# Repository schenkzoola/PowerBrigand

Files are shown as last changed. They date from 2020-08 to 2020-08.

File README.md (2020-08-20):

# PowerBrigand

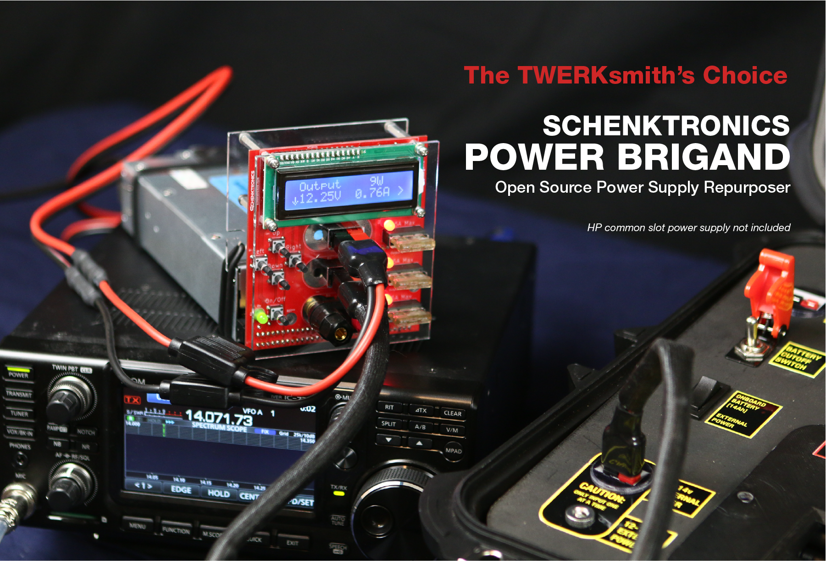
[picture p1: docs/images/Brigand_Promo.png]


## About

### How can I get it?

Well, you can build one yourself from the source files here, or better yet, you can join the waitlist for a kit from my Tindie store below:
[https://www.tindie.com/products/schenktronics/power-brigand/](https://www.tindie.com/products/schenktronics/power-brigand/)
The parts for the first batch of kits have been ordered! 

### What is it?

Power Brigand is a module that attaches to HP common slot power supplies that are normally used in servers.  It has connectors and/or binding posts to bring 12v power to your devices.  It also has controls which allow you to turn the power supply on and off, as well as display parameters such as voltage, current, and temperature from the i2c bus on the power supply.

### Why?

After leaving the cryptocurrency mining scene, I had quite a few of these power supplies.  They are plentiful on eBay, and therefore inexpensive.  I felt it wasn't worth my time trying to sell them, and wanted a way to repurpose them.  I was unimpressed with the typical breakout board available from eBay and Aliexpress.

### How?

I found a few resources to start with.  [This one](http://colintd.blogspot.com/2016/10/hacking-hp-common-slot-power-supplies.html) discussed the supply, and compared it to a similar Murata power supply.

The best source of information I found was [this github repo](https://github.com/raplin/DPS-1200FB) where the author, DrTune, reverse engineered a power supply by decompiling the firmware from the internal microcontroller.  DrTune created some sample python code to read and write data to and from the I2C bus.  This gave me information on which registers to query for the data.

Using an arduino nano, a bus pirate, and DrTune's python code as a guide, I was able to successfully read the I2C bus.  This encouraged me to create a PCB with an LCD, output terminals, and fuses.

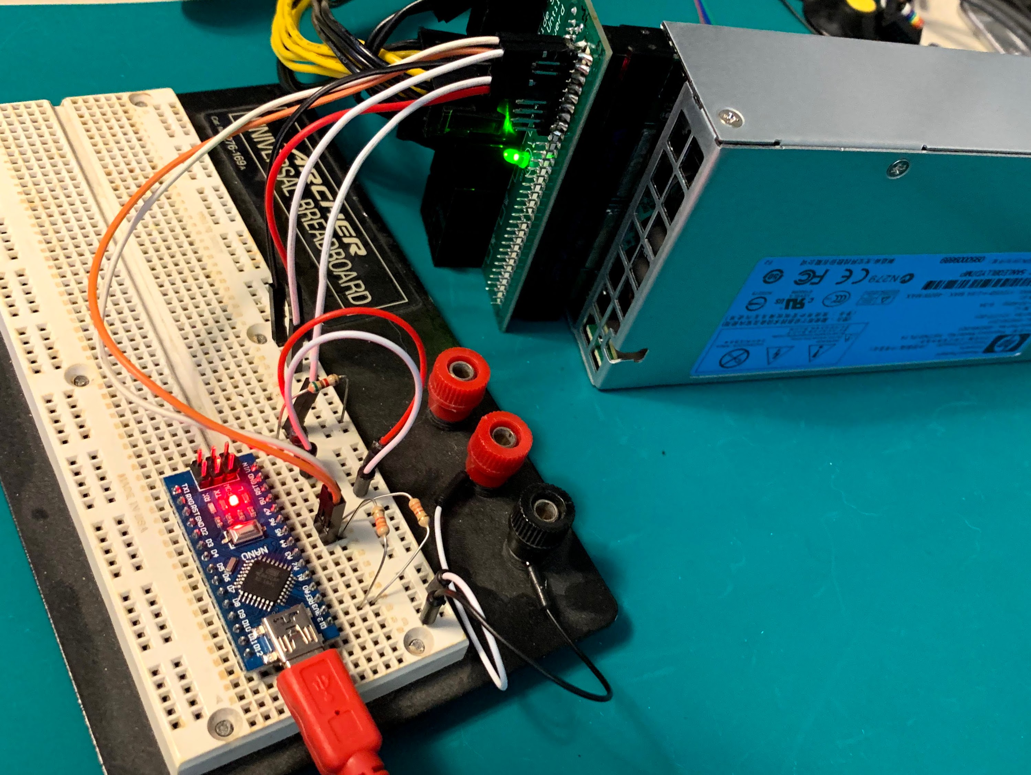
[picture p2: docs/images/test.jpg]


## Hardware

### Common Slot Power Supply

This is the heart of the Power Brigand, it won't work without one.
There are at least four commonly available versions of these power supplies: 460W, 750W, and two different 1200W versions.

#### 460W

This is the smallest of the power supplies, and the quietest.  Despite its small size, it is capable of producing 38.3A.  My testing has shown that this has the quietest fan, and the most sensitive current measurement capability.

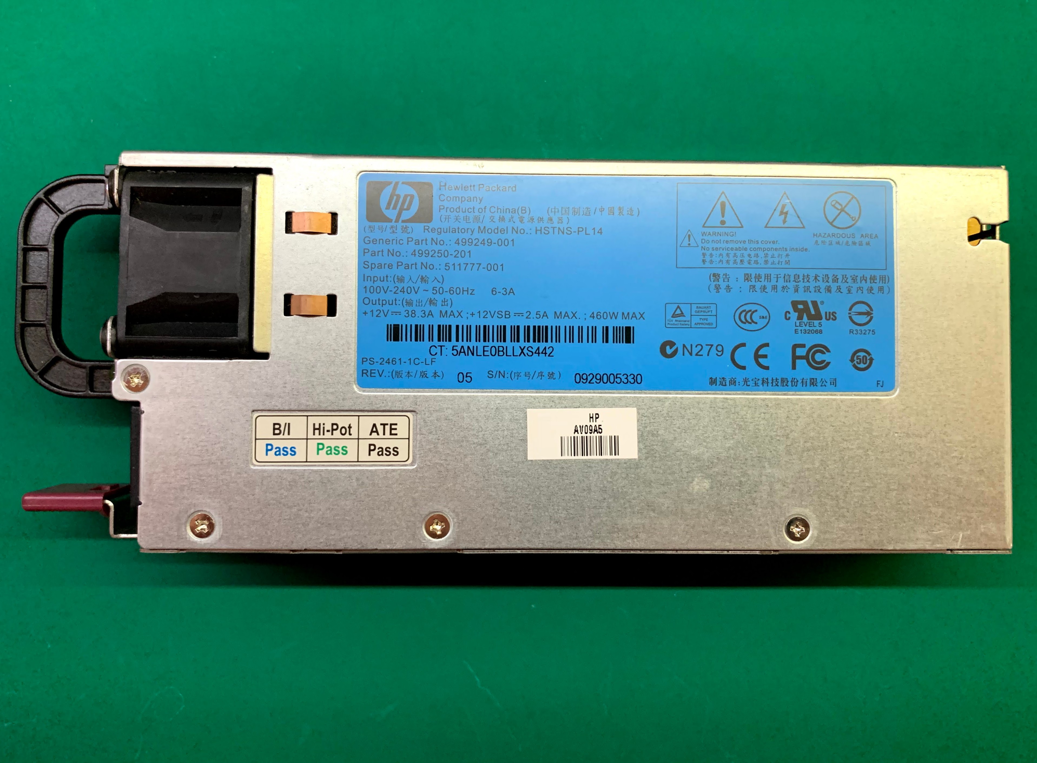
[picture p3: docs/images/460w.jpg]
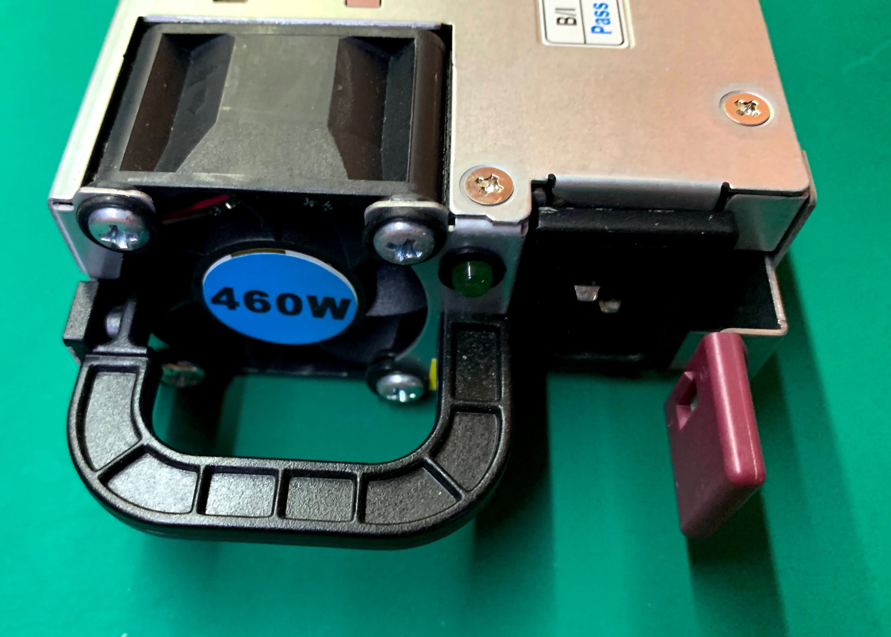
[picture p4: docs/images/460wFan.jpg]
 

#### 750W

This is the middle size power supply.  It can produce 62.5A.  Its fan is noisier than the 460W, and the minimum current it can accurately display is about 5A.

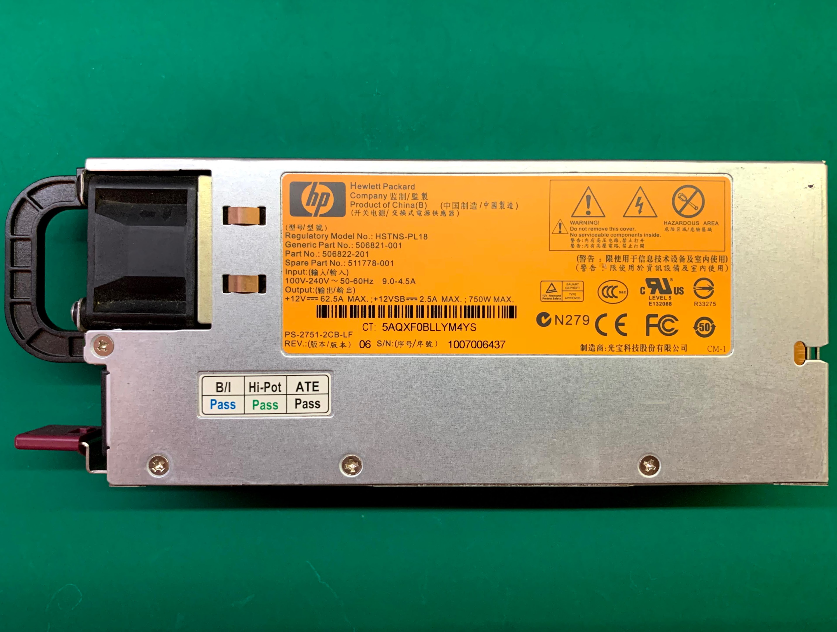
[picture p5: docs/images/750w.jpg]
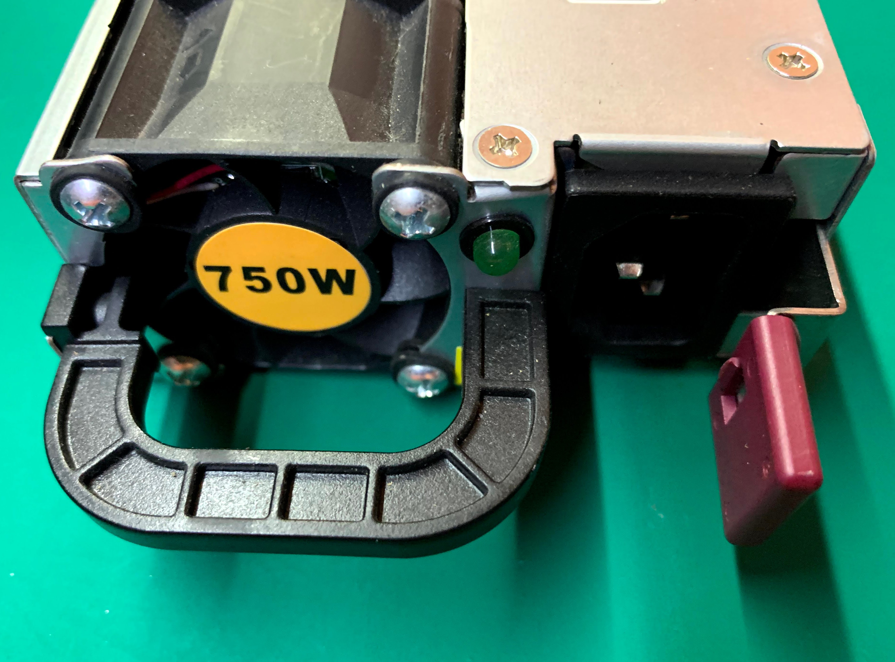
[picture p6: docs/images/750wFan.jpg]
 

#### 1200W

There are two 1200W power supplies, one is higher efficiency than the other.  They are sensitive to the input voltage.  At 120V they can only produce 75A. They require a 200V-240V power source to produce their full capability of 100A.  These power supplies also have a minimum accurate current display of about 5A, and they typically have noisier fans than the others.

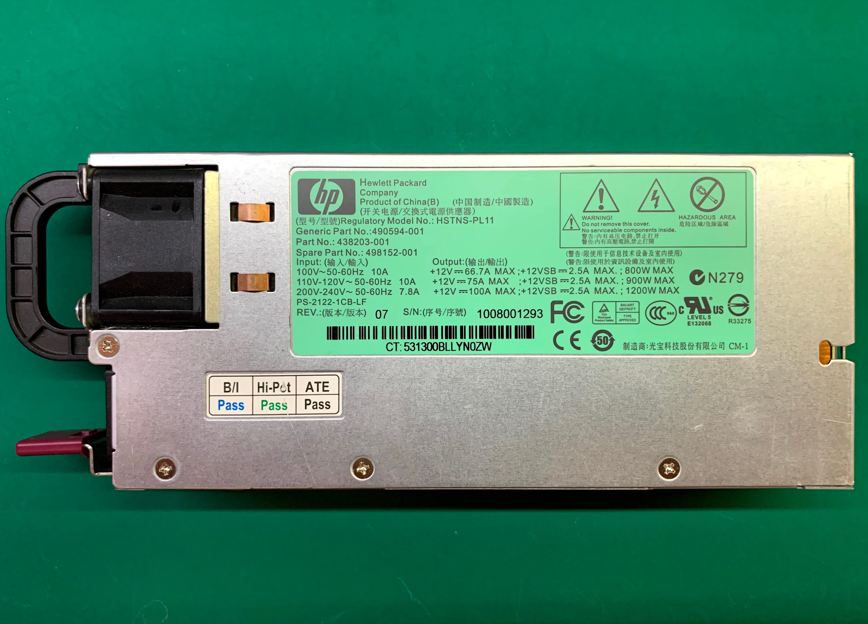
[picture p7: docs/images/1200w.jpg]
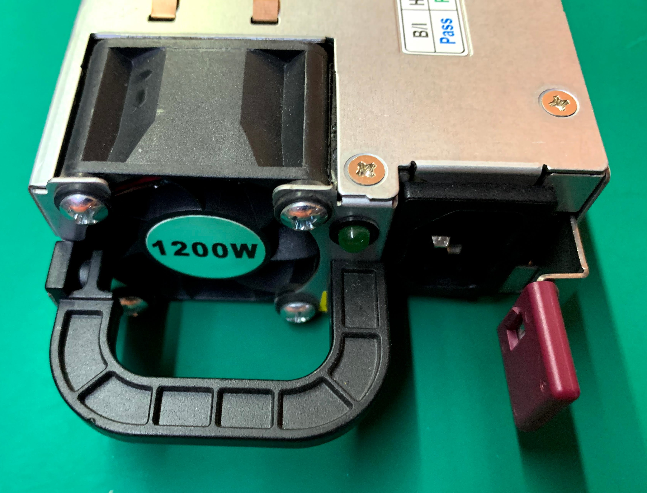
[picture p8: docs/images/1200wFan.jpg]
 
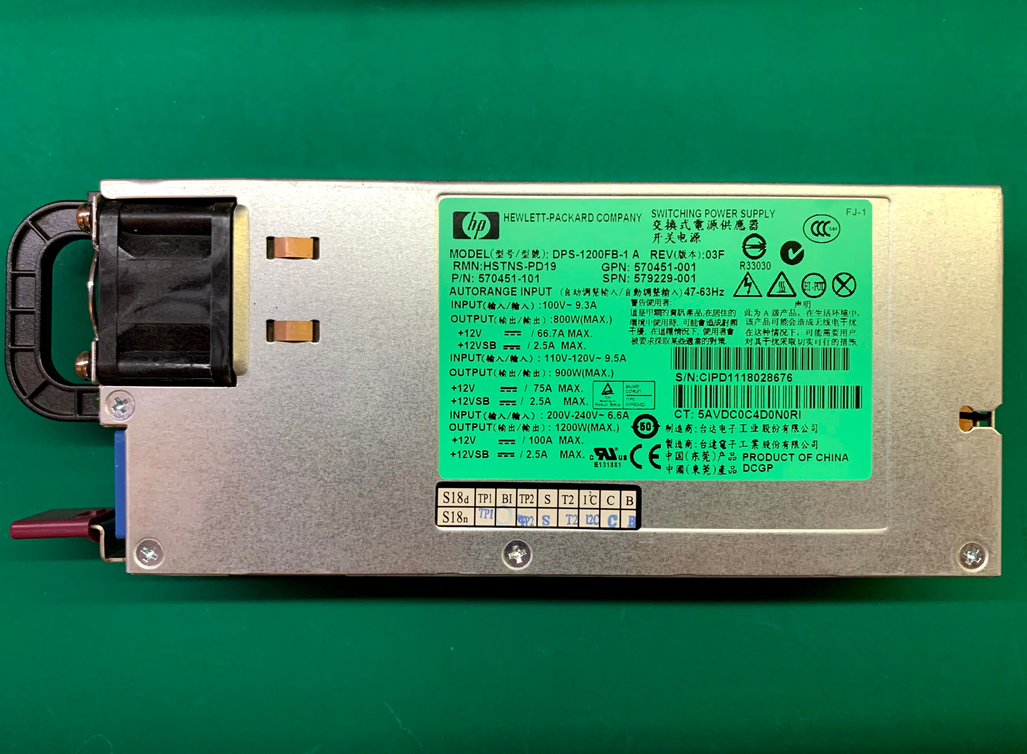
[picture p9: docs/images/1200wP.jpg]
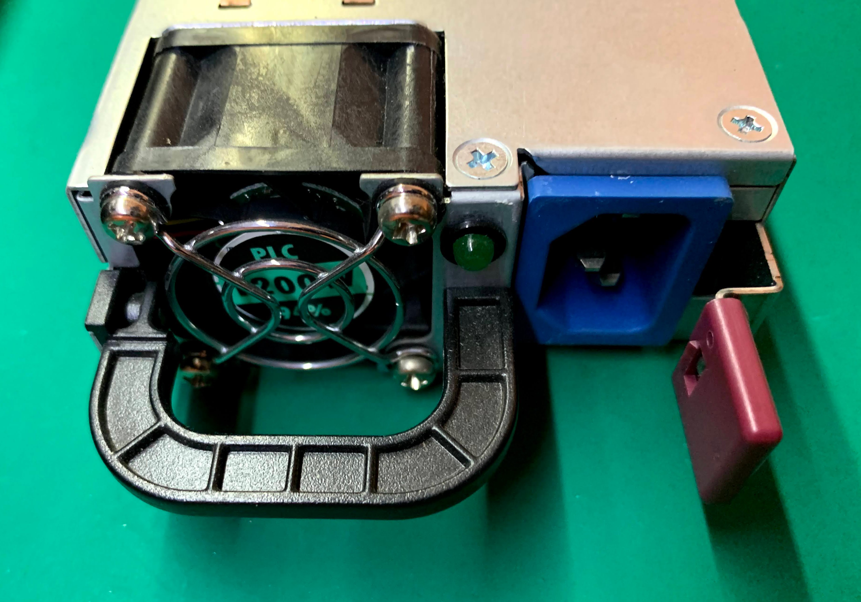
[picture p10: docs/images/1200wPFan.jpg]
 

### Power Brigand

The power brigand consists of a main PCB which integrates the edge card connector, fuses, buttons, LED's, LCD, Arduino Nano, and other supporting components.

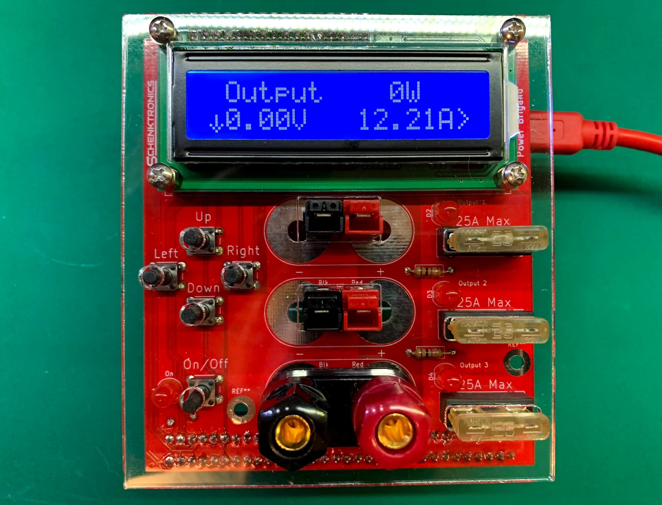
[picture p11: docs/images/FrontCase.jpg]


#### Fused Outputs

There are three 25A fused outputs, for 75A total output capability.  Each fuse has an LED next to it to indicate whether there is voltage after the fuse.  If one of the LED's is not lit, there is a good chance that fuse is blown.  The fuse holders are designed to accommodate standard automotive blade style fuses.

The outputs can be configured with either binding posts, or Anderson powerpole connectors.  A typical configuration would have two sets of powerpole connectors and one pair of binding posts.

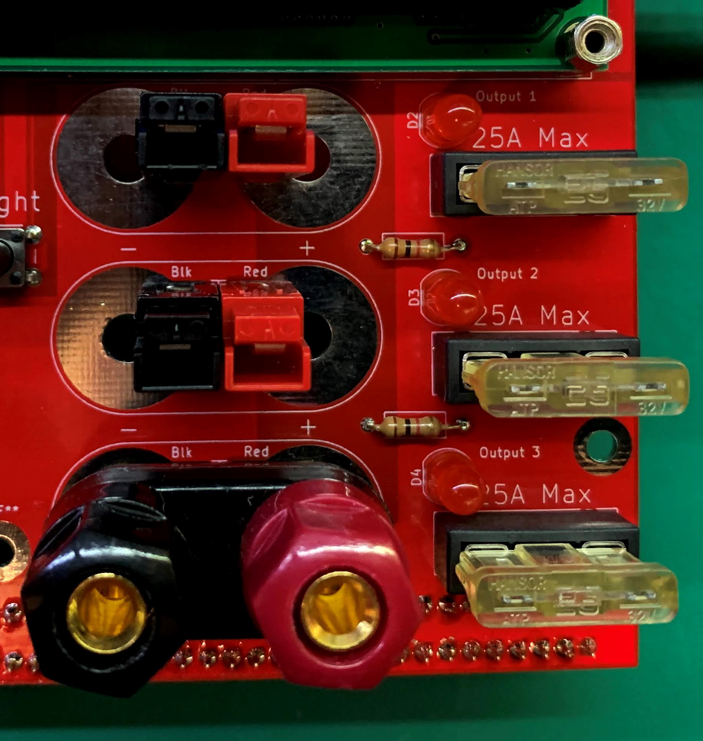
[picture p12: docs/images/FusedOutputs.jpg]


#### Power Button

On the lower left, there is a power button.  Press this button once to turn on the outputs.  Hold this button to turn off the outputs.  The LED next to the power button will illuminate when the outputs are commanded to turn on.

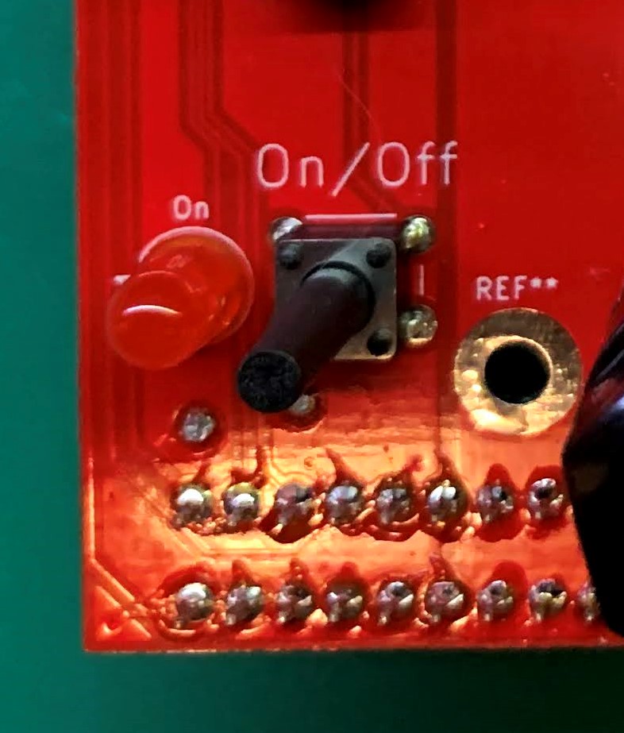
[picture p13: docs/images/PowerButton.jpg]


#### LCD and navigation buttons

The LCD is where the information is displayed.  There are four push buttons just below the left of the LCD.  If you see an arrow on the display, it indicates you can push one of these four buttons to navigate.  If you see an arrow pointing up, that means you can press the "up" button.  If you see an arrow pointing to the right, that means you can press the "right" button, and so on.

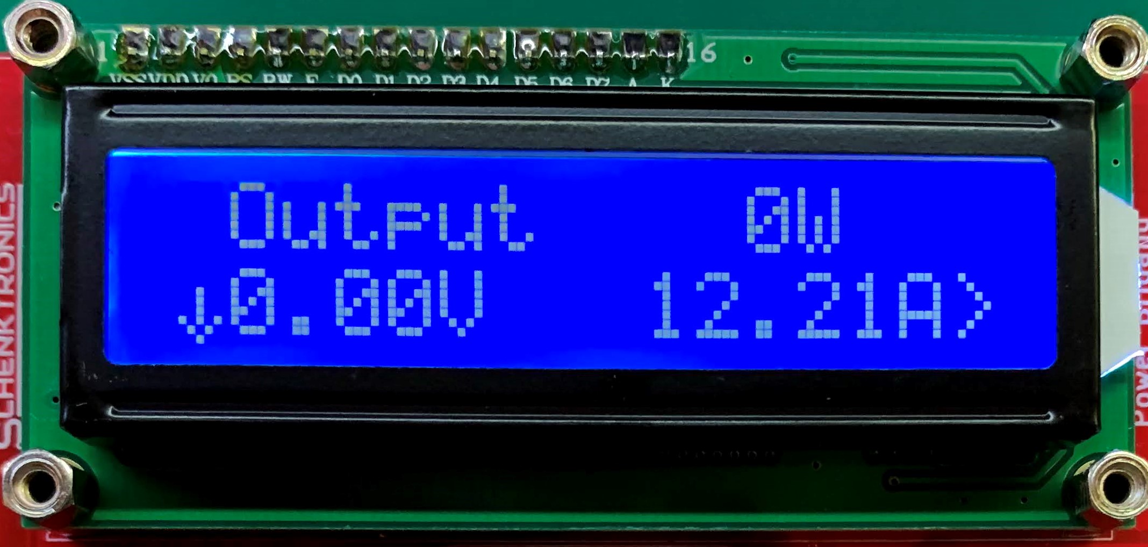
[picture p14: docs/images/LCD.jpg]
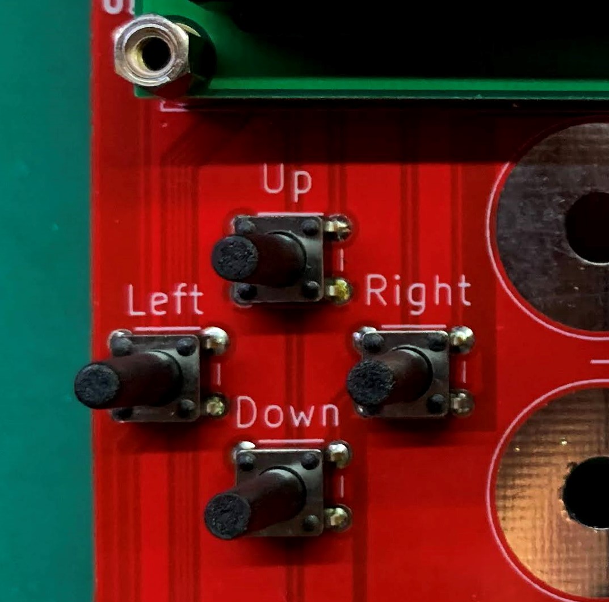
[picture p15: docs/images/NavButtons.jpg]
 

#### Arduino Nano

The Arduino Nano compatible module is the "brains" of the unit.  It reads the I2C bus on the power supply, commands it on and off, writes data to the LCD, and handles the buttons.  The software is written and C and can easily be modified using the Arduino IDE.

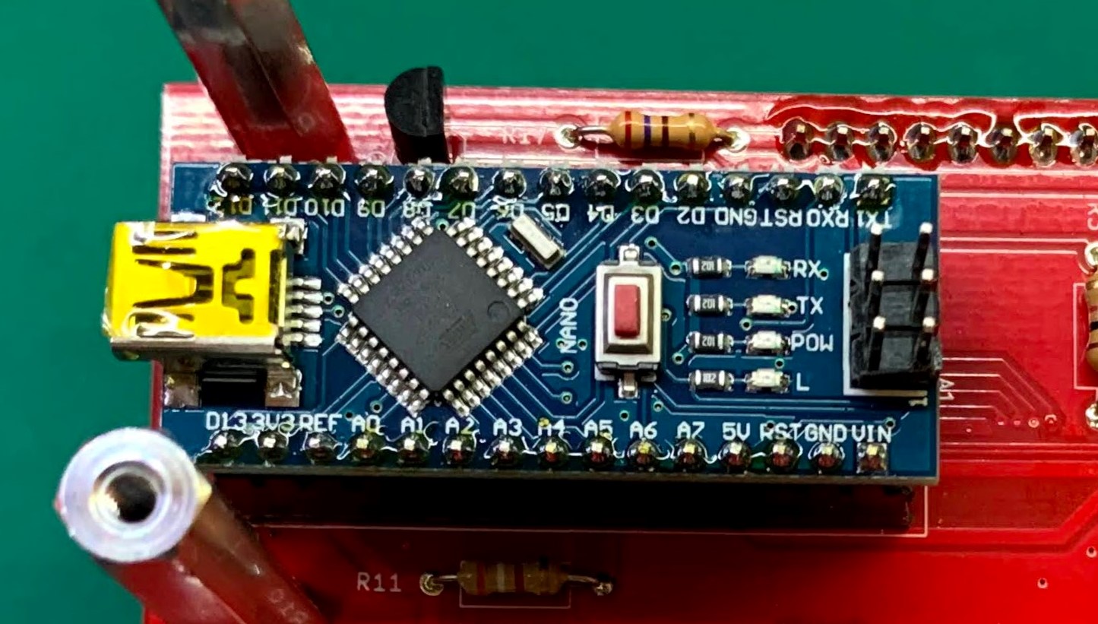
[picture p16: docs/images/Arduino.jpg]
 

<br />This work is licensed under a <a rel="license" href="http://creativecommons.org/licenses/by-nc-sa/4.0/">Creative Commons Attribution-NonCommercial-ShareAlike 4.0 International License</a>.

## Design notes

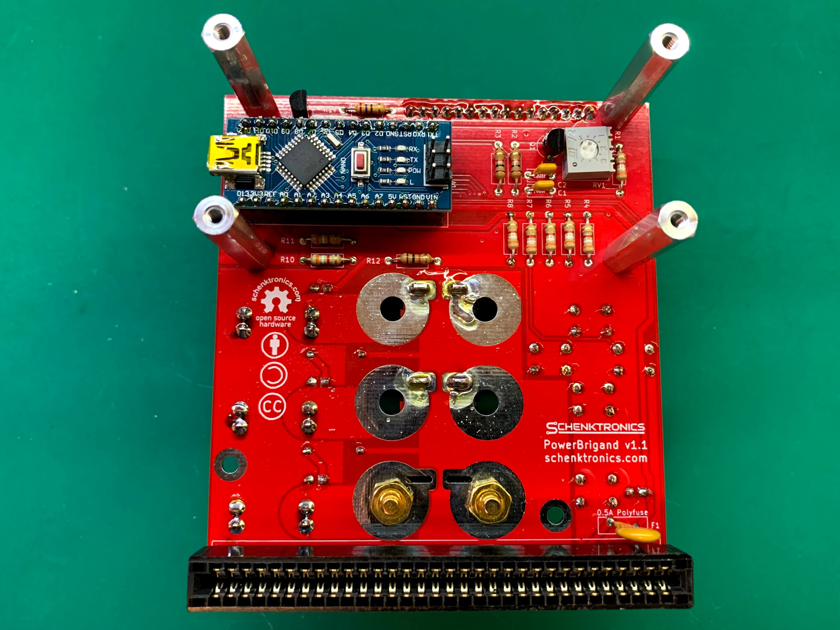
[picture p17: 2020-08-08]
docs/images/BackNoCase.jpg

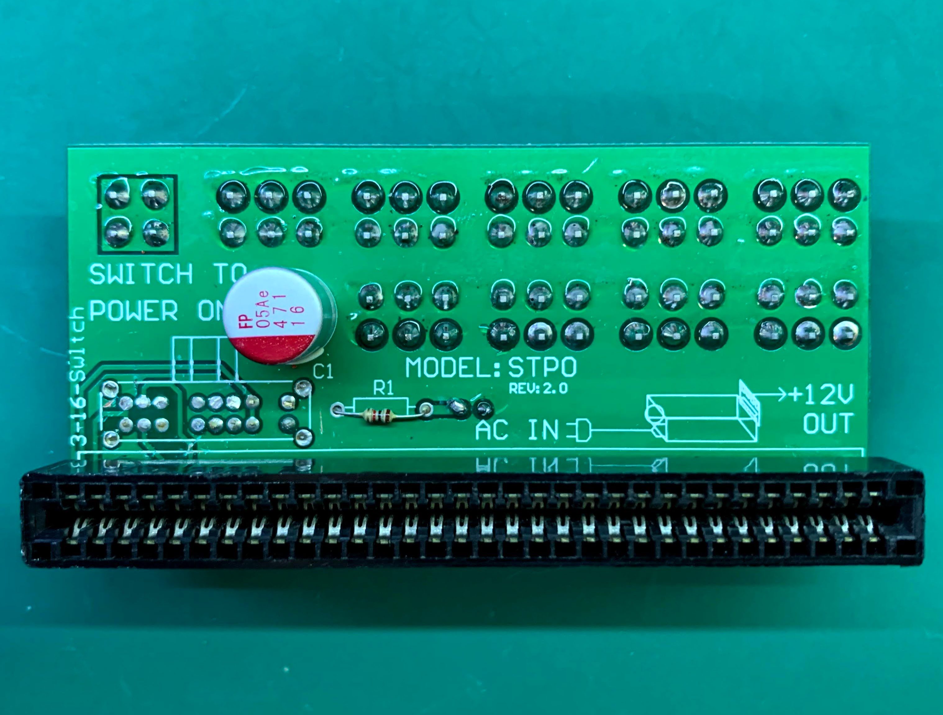
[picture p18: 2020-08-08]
docs/images/generic.jpg

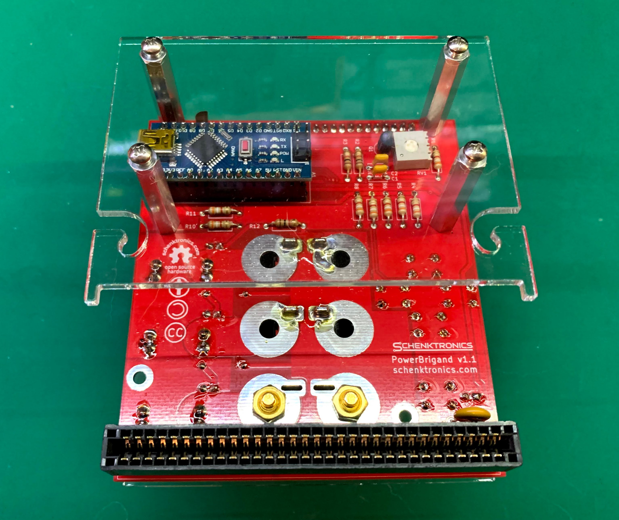
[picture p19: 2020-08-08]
docs/images/BackCase.jpg

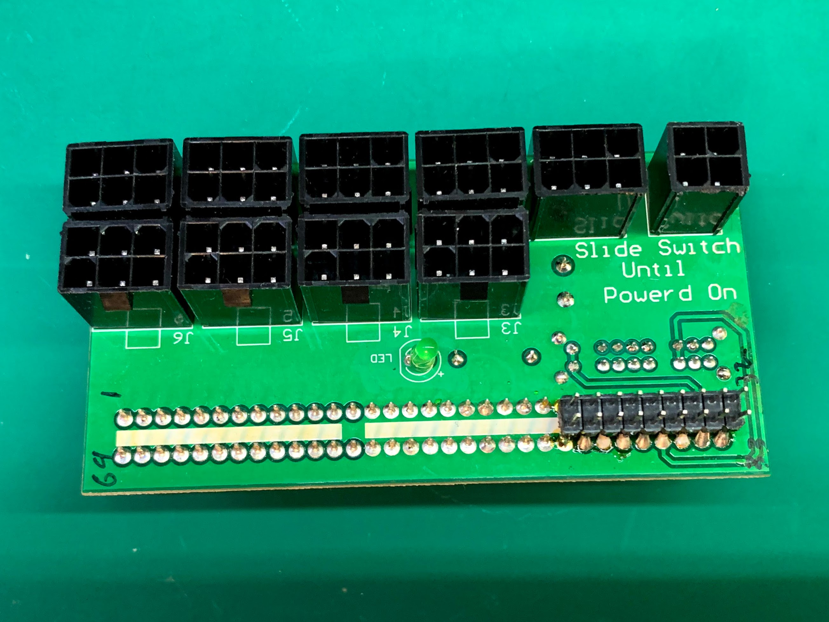
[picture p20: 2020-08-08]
docs/images/genericFront.jpg

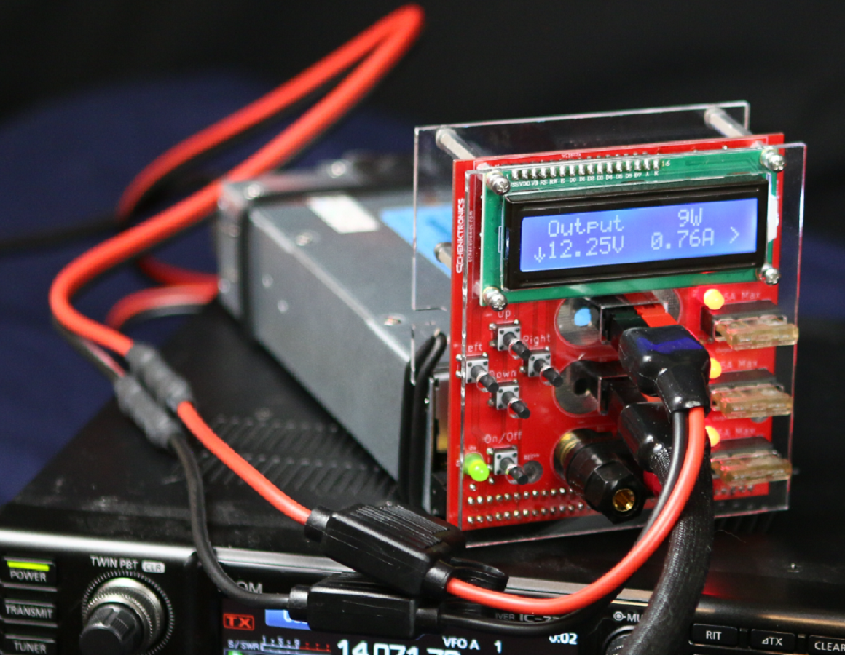
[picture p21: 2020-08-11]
docs/images/Brigand_Promo_cropped.png

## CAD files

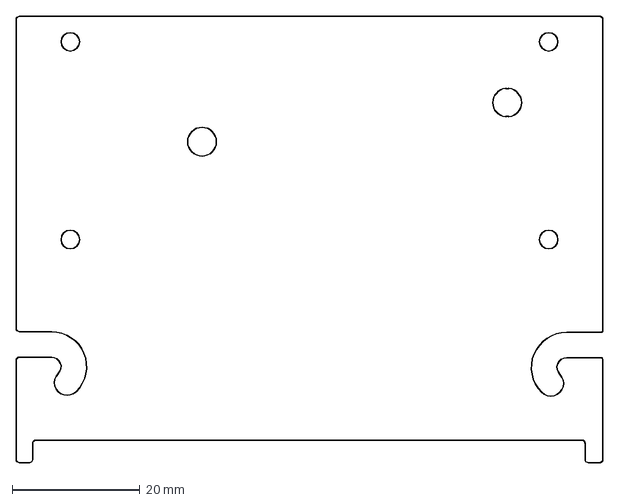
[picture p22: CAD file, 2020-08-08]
PowerBrigand-Case/backplate.dxf
92.0 x 70.0 mm

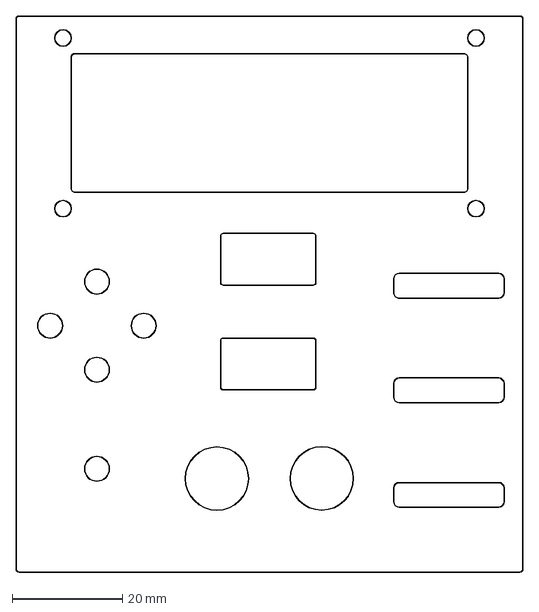
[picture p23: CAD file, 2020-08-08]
PowerBrigand-Case/faceplate_2anderson_1BindingPost.dxf
92.0 x 101.0 mm

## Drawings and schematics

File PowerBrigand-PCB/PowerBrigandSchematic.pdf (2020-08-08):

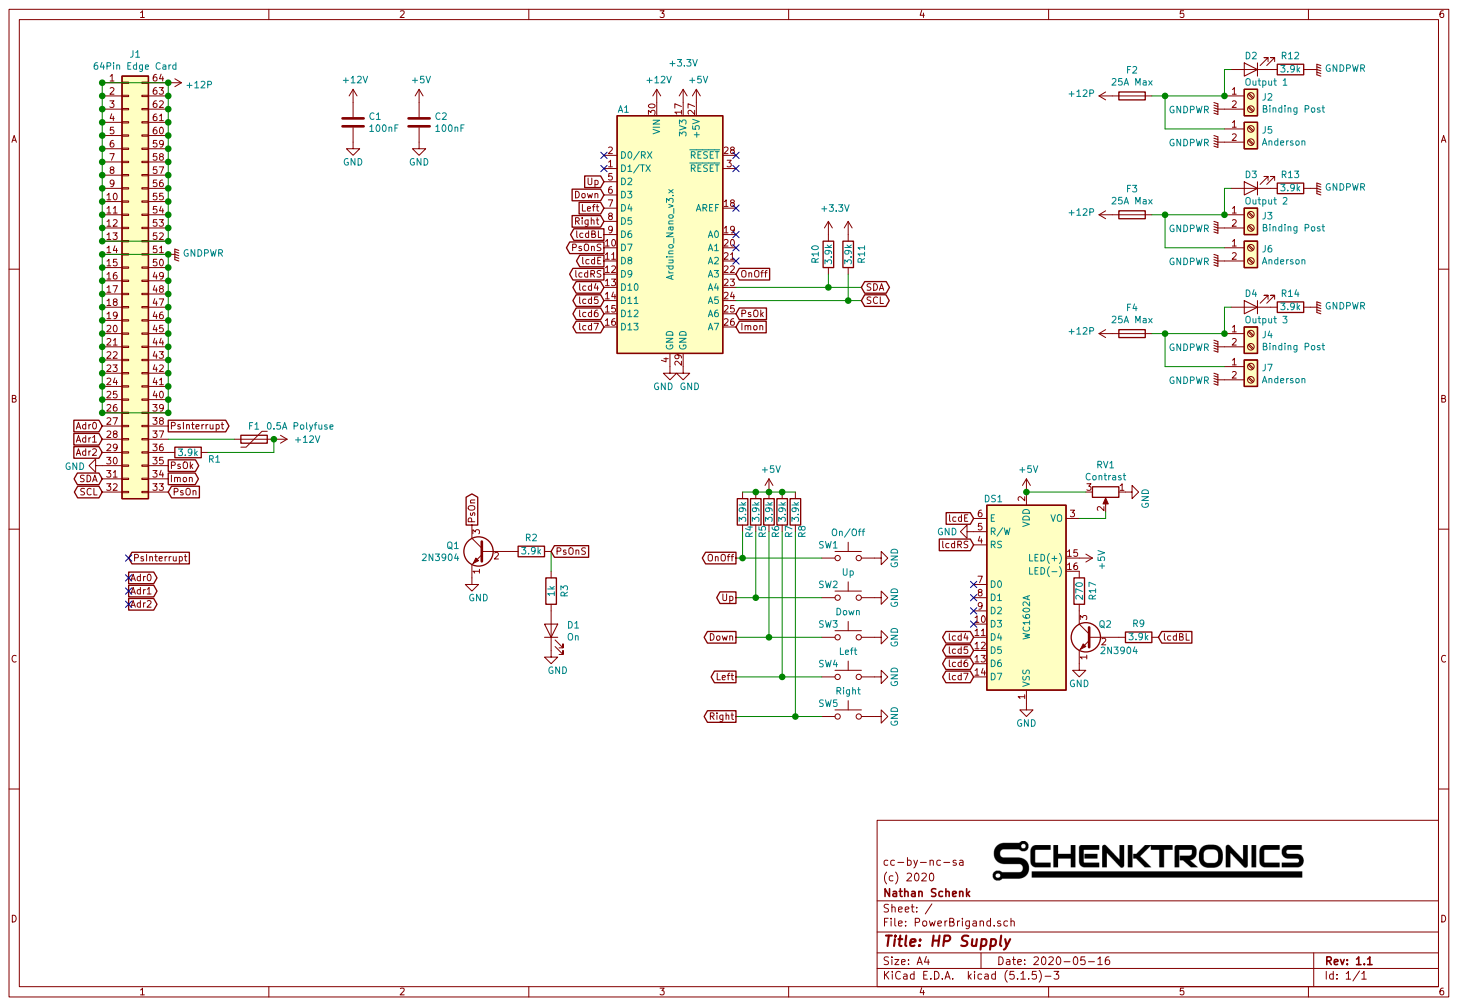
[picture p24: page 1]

3 | 62
4 | 61
5 | 60
6 | 59
7 | 58
8 | 57
9 | 56
10 | 55
11 | 54
12 | 53
13 | 52

15 | 50
16 | 49
17 | 48
18 | 47
19 | 46
20 | 45
21 | 44
22 | 43
23 | 42
24 | 41
25 | 40
26 | 39

File: PowerBrigand.sch Sheet: / Nathan Schenk

Id: 1/1 Title: HP Supply

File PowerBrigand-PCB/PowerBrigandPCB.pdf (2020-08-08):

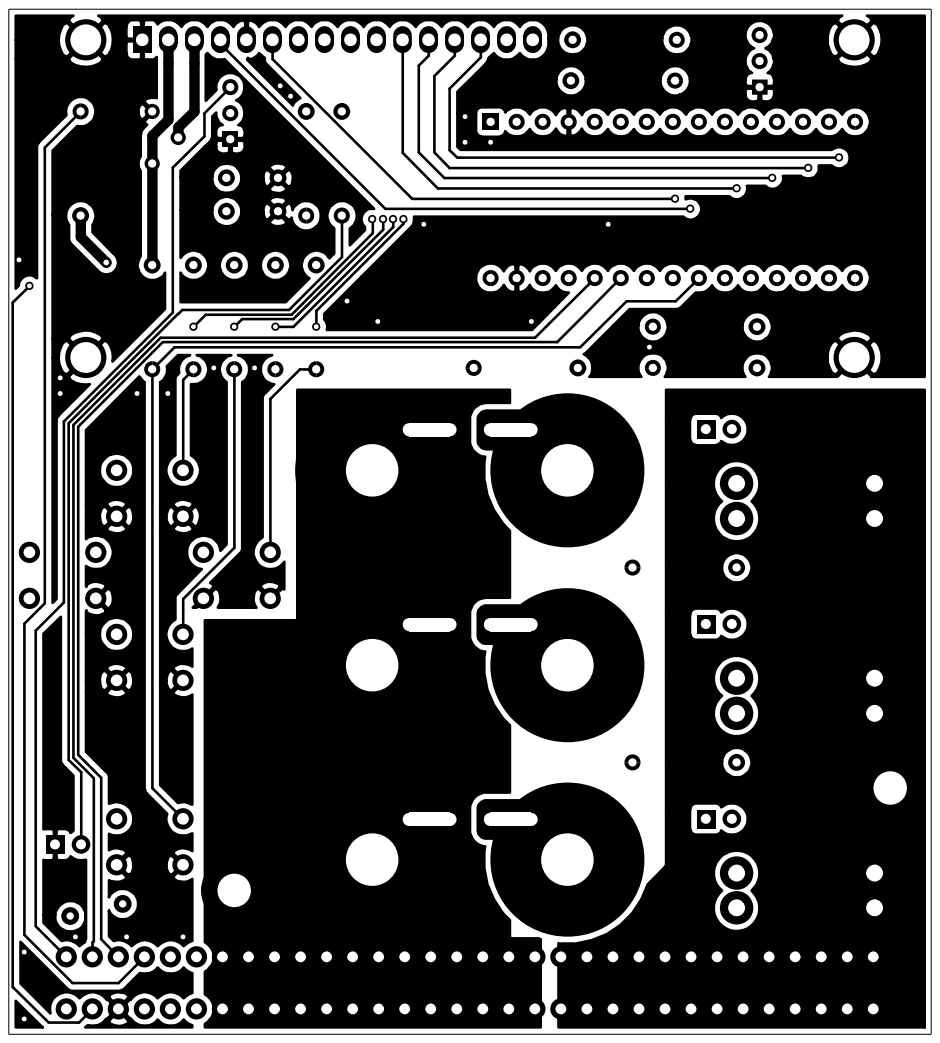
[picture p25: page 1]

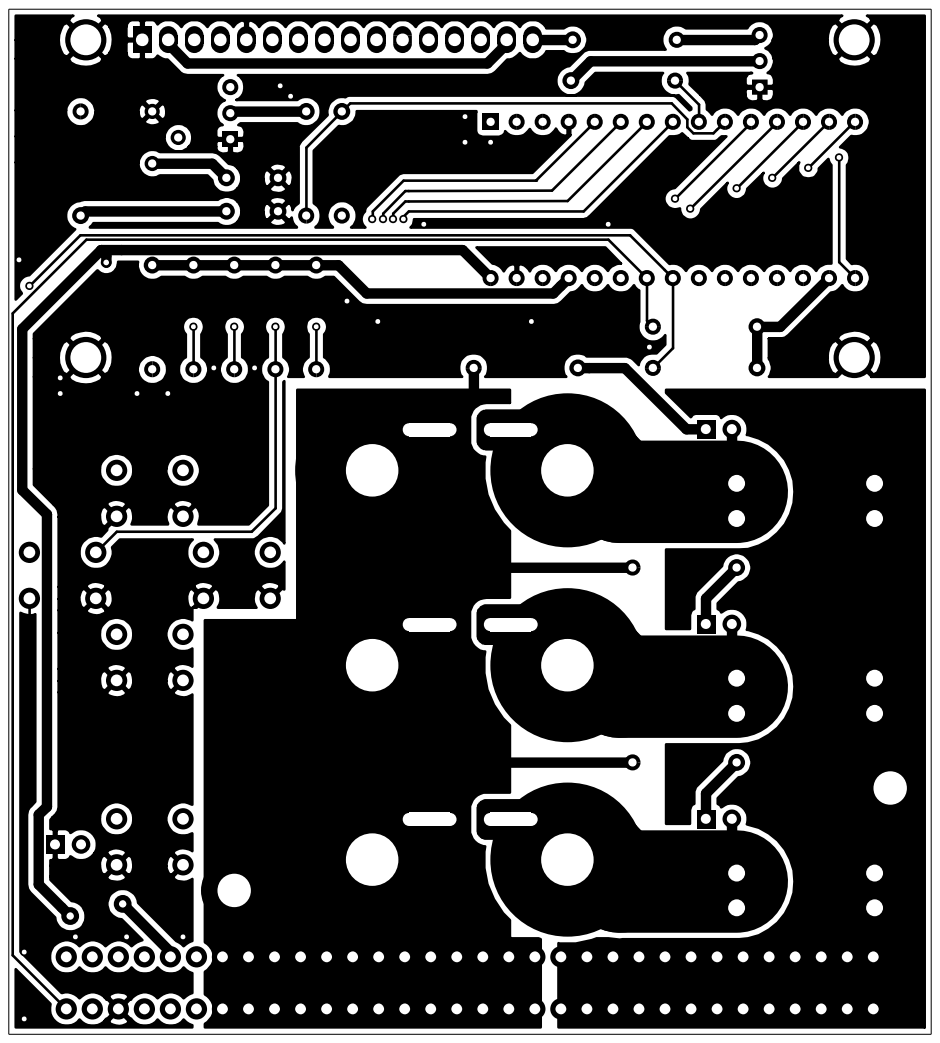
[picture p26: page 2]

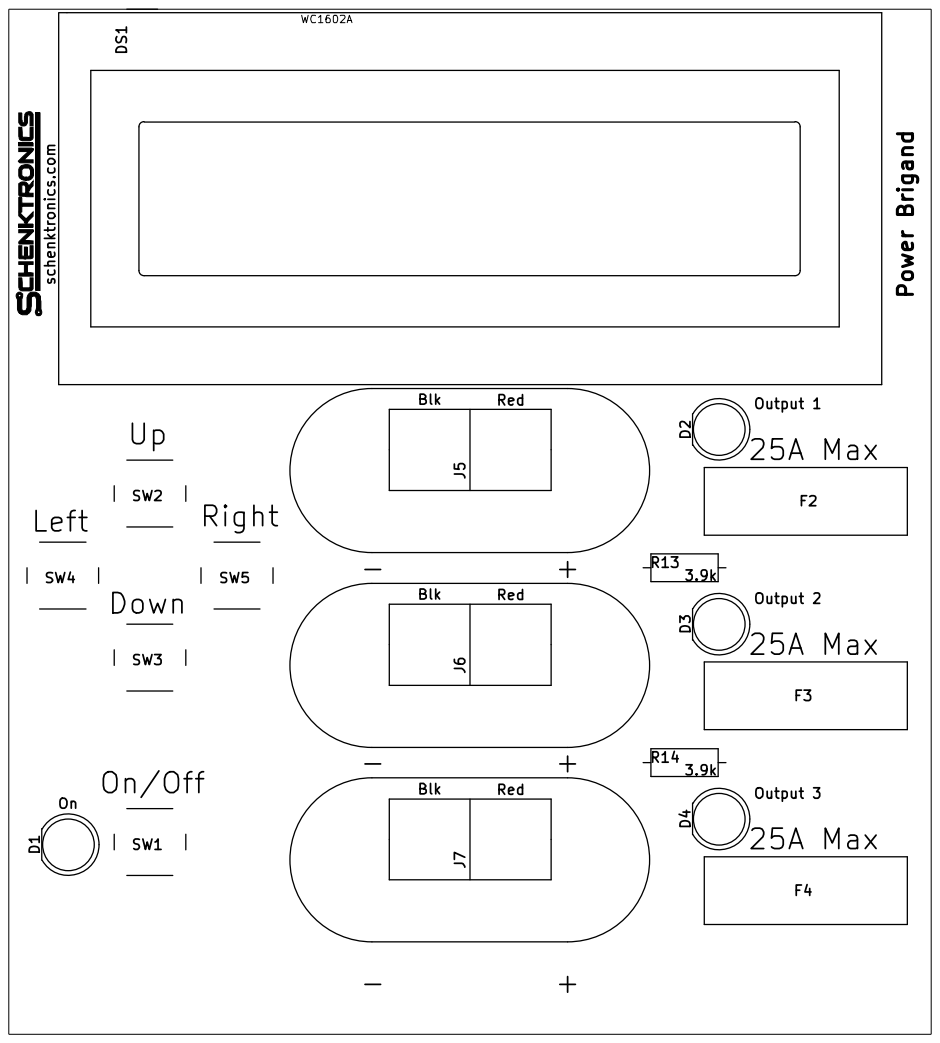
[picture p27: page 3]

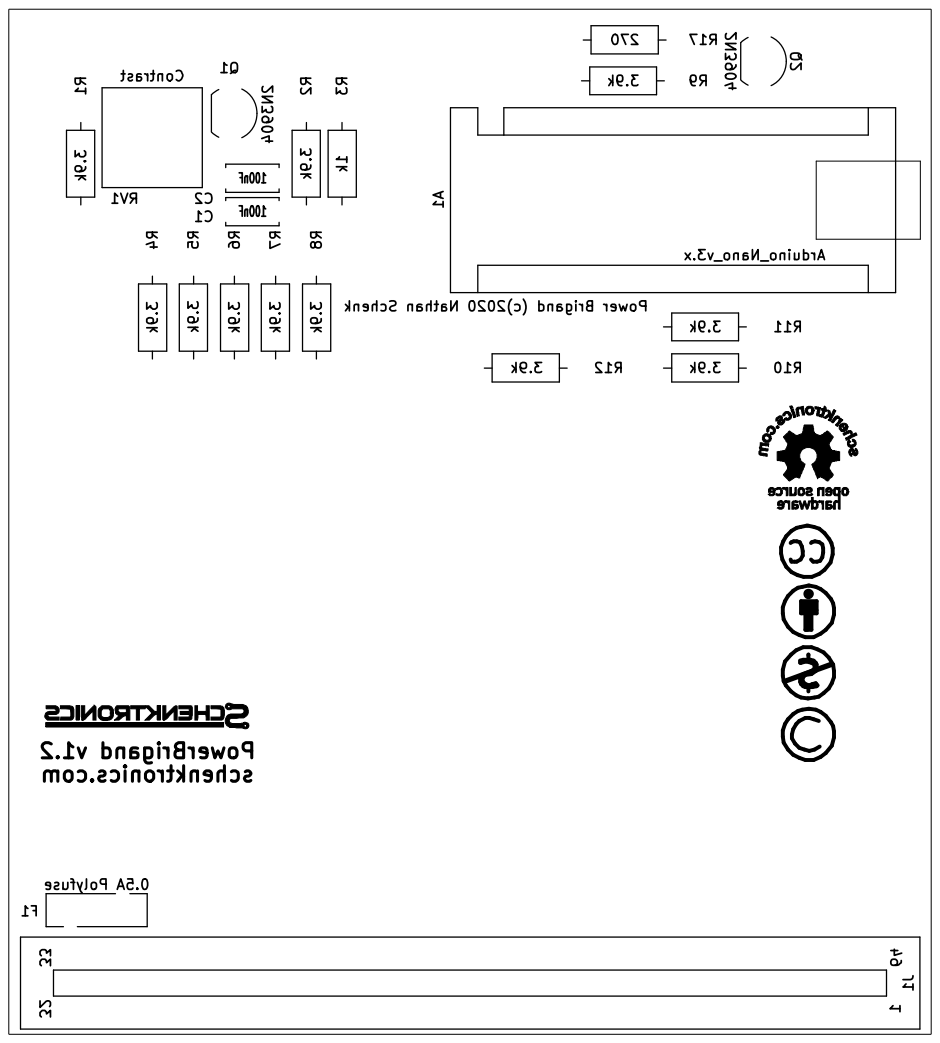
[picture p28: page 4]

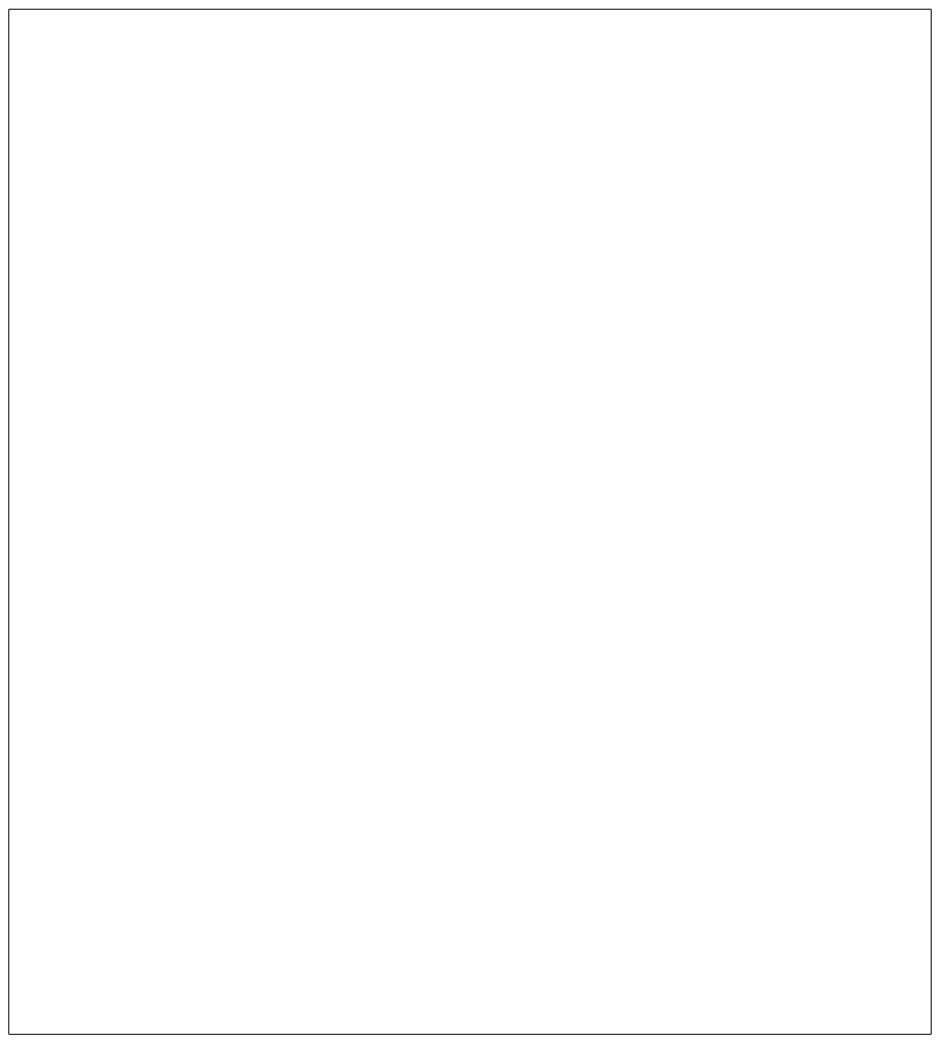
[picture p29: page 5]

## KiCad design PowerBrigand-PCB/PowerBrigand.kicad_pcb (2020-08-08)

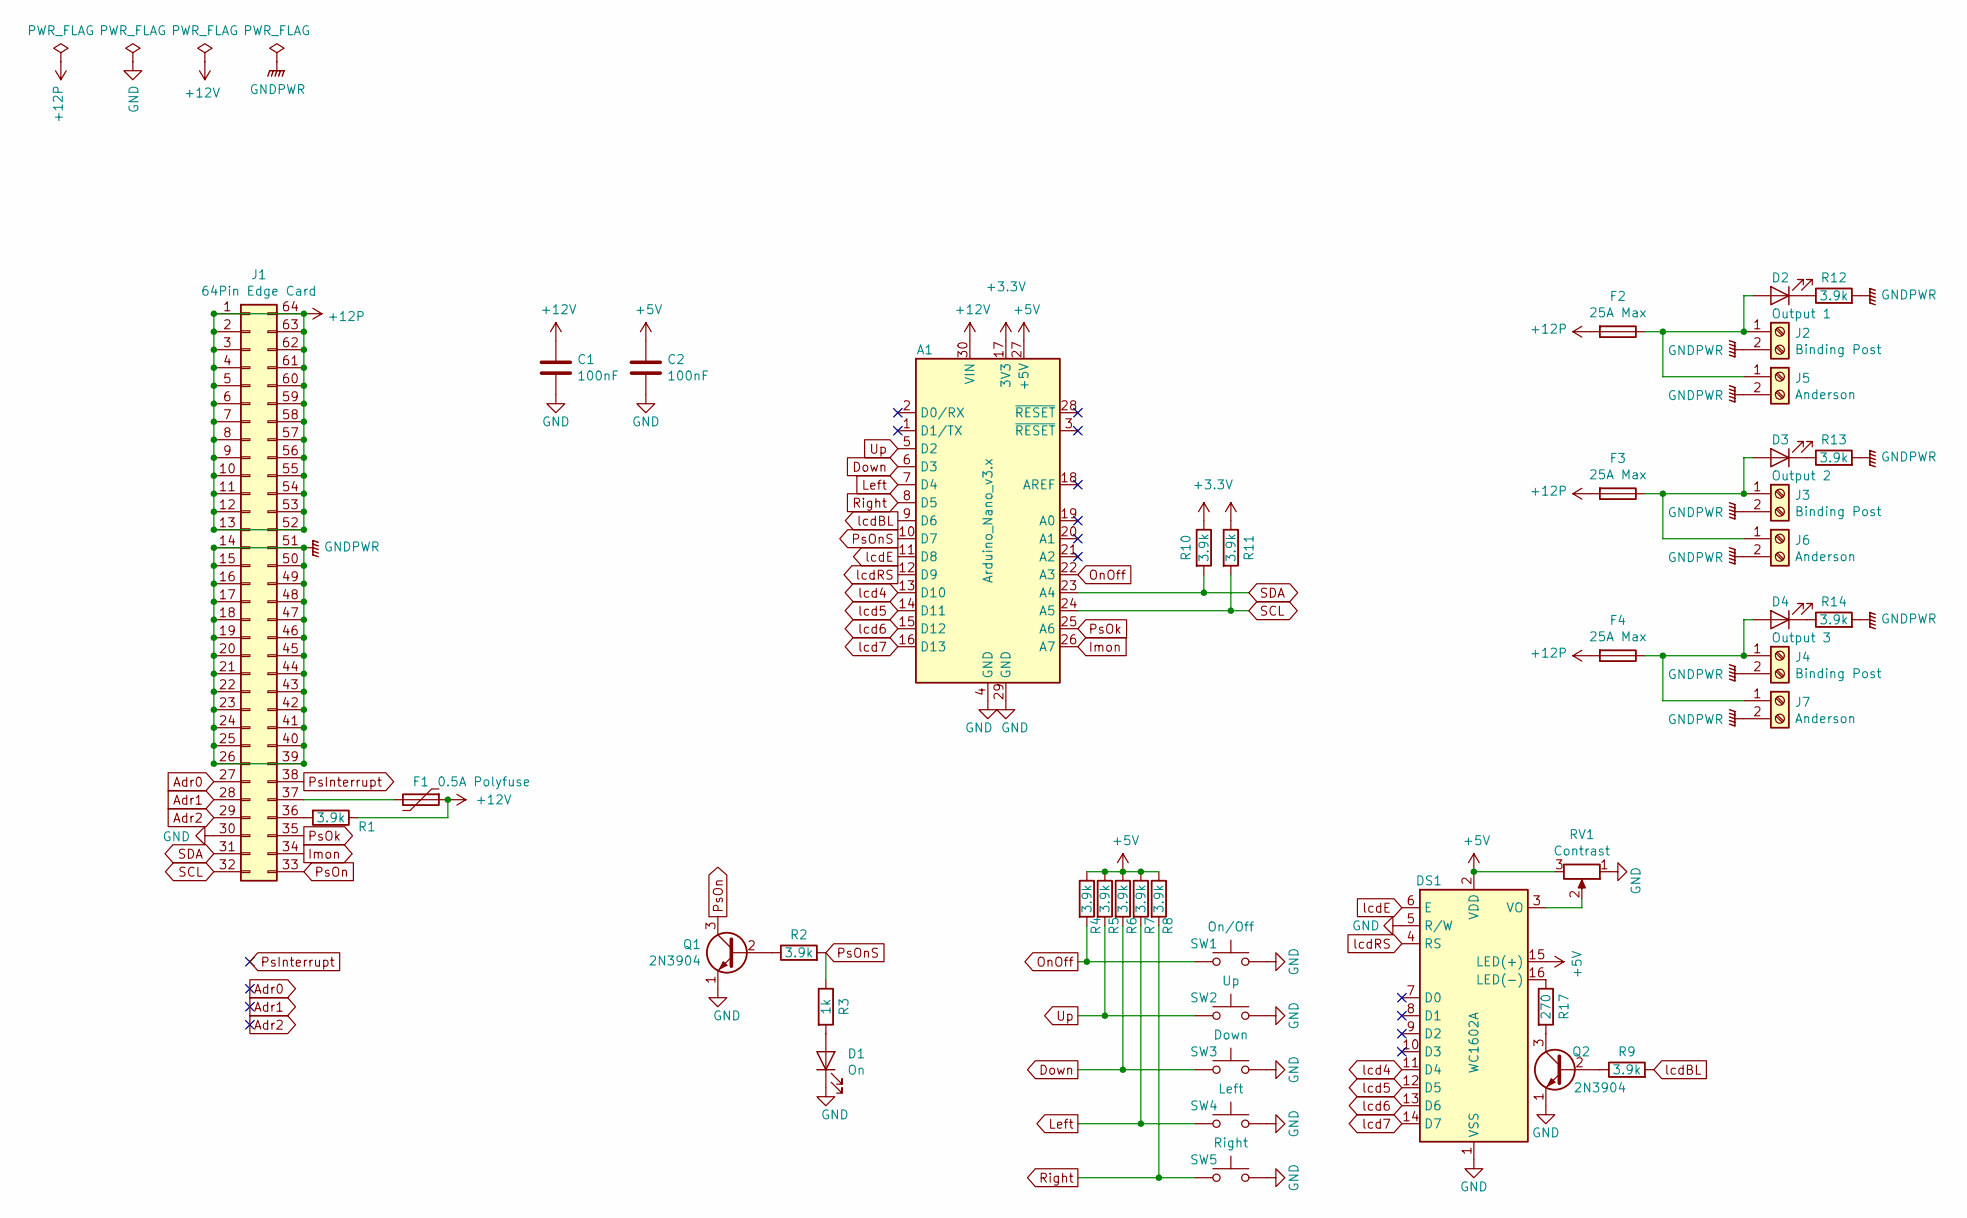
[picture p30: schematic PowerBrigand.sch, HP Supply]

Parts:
A1: Arduino_Nano_v3.x; Arduino_Nano
C1, C2: 100nF; C_Disc_D5.0mm_W2.5mm_P5.00mm
D1: On; LED_D5.0mm
D2: Output 1; LED_D5.0mm
D3: Output 2; LED_D5.0mm
D4: Output 3; LED_D5.0mm
DS1: WC1602A; WC1602A_3mmHoles
F1: 0.5A Polyfuse; Fuse_Bourns_MF-RHT100
F2, F3, F4: 25A Max; FuseHolder_Keystone_3557-2
J1: 64Pin Edge Card; FCI_10046971-001LF
J2, J3, J4: Binding Post; BindingPost_Keystone_7019
J5, J6, J7: Anderson; ASMPV45-1X2-RK
Q1, Q2: 2N3904; TO-92_Inline_Wide
R1, R2, R4, R5, R6, R7, R8, R9, R10, R11, R12, R13, R14: 3.9k; R_Axial_DIN0207_L6.3mm_D2.5mm_P10.16mm_Horizontal
R3: 1k; R_Axial_DIN0207_L6.3mm_D2.5mm_P10.16mm_Horizontal
R17: 270; R_Axial_DIN0207_L6.3mm_D2.5mm_P10.16mm_Horizontal
RV1: Contrast; Potentiometer_Bourns_3386P_Vertical
SW1: On/Off; SW_PUSH_6mm_H13mm
SW2: Up; SW_PUSH_6mm_H13mm
SW3: Down; SW_PUSH_6mm_H13mm
SW4: Left; SW_PUSH_6mm_H13mm
SW5: Right; SW_PUSH_6mm_H13mm

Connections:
+3V3: A1.17 (3V3), R10.1, R11.1
+5V: A1.27 (+5V), C2.1, DS1.2 (VDD), DS1.15 (LED(+)), R4.1, R5.1, R6.1, R7.1, R8.1, RV1.3
+12P: F2.2, F3.2, F4.2, J1.1, J1.2, J1.3, J1.4, J1.5, J1.6, J1.7, J1.8, J1.9, J1.10, J1.11, J1.12, J1.13, J1.52, J1.53, J1.54, J1.55, J1.56, J1.57, J1.58, J1.59, J1.60, J1.61, J1.62, J1.63, J1.64
+12V: A1.30 (VIN), C1.1, F1.1, R1.1
Adr0: J1.27
Adr1: J1.28
Adr2: J1.29
Down: A1.6 (D3), R6.2, SW3.1
GND: A1.4 (GND), A1.29 (GND), C1.2, C2.2, D1.1 (K), DS1.1 (VSS), DS1.5 (R/W), J1.30, Q1.1 (E), Q2.1 (E), RV1.1, SW1.2, SW2.2, SW3.2, SW4.2, SW5.2
GNDPWR: J1.14, J1.15, J1.16, J1.17, J1.18, J1.19, J1.20, J1.21, J1.22, J1.23, J1.24, J1.25, J1.26, J1.39, J1.40, J1.41, J1.42, J1.43, J1.44, J1.45, J1.46, J1.47, J1.48, J1.49, J1.50, J1.51, J2.2, J3.2, J4.2, J5.2, J6.2, J7.2, R12.2, R13.2, R14.2
Imon: A1.26 (A7), J1.34
Left: A1.7 (D4), R7.2, SW4.1
unnamed: D1.2 (A), R3.2
unnamed: D2.1 (K), R12.1
unnamed: D2.2 (A), F2.1, J2.1, J5.1
unnamed: D3.1 (K), R13.1
unnamed: D3.2 (A), F3.1, J3.1, J6.1
unnamed: D4.1 (K), R14.1
unnamed: D4.2 (A), F4.1, J4.1, J7.1
unnamed: DS1.3 (VO), RV1.2
unnamed: DS1.16 (LED(-)), R17.1
unnamed: F1.2, J1.37
unnamed: J1.36, R1.2
unnamed: Q1.2 (B), R2.1
unnamed: Q2.2 (B), R9.1
unnamed: Q2.3 (C), R17.2
OnOff: A1.22 (A3), R4.2, SW1.1
PsInterrupt: J1.38
PsOk: A1.25 (A6), J1.35
PsOn: J1.33, Q1.3 (C)
PsOnS: A1.10 (D7), R2.2, R3.1
Right: A1.8 (D5), R8.2, SW5.1
SCL: A1.24 (A5), J1.32, R11.2
SDA: A1.23 (A4), J1.31, R10.2
Up: A1.5 (D2), R5.2, SW2.1
lcd4: A1.13 (D10), DS1.11 (D4)
lcd5: A1.14 (D11), DS1.12 (D5)
lcd6: A1.15 (D12), DS1.13 (D6)
lcd7: A1.16 (D13), DS1.14 (D7)
lcdBL: A1.9 (D6), R9.2
lcdE: A1.11 (D8), DS1.6 (E)
lcdRS: A1.12 (D9), DS1.4 (RS)

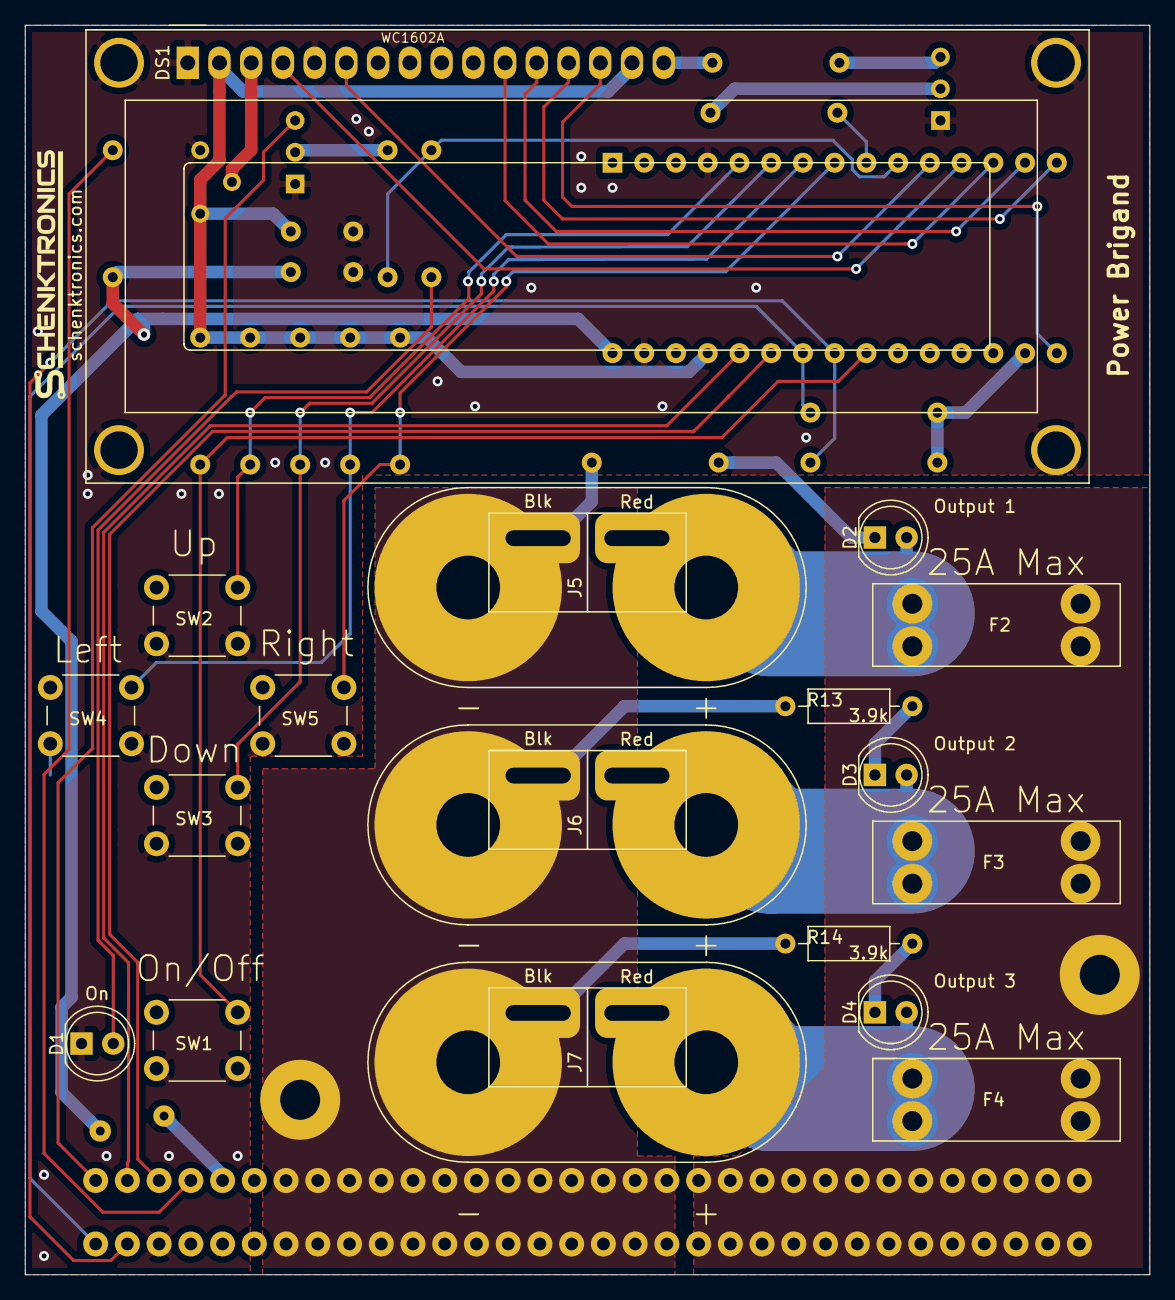
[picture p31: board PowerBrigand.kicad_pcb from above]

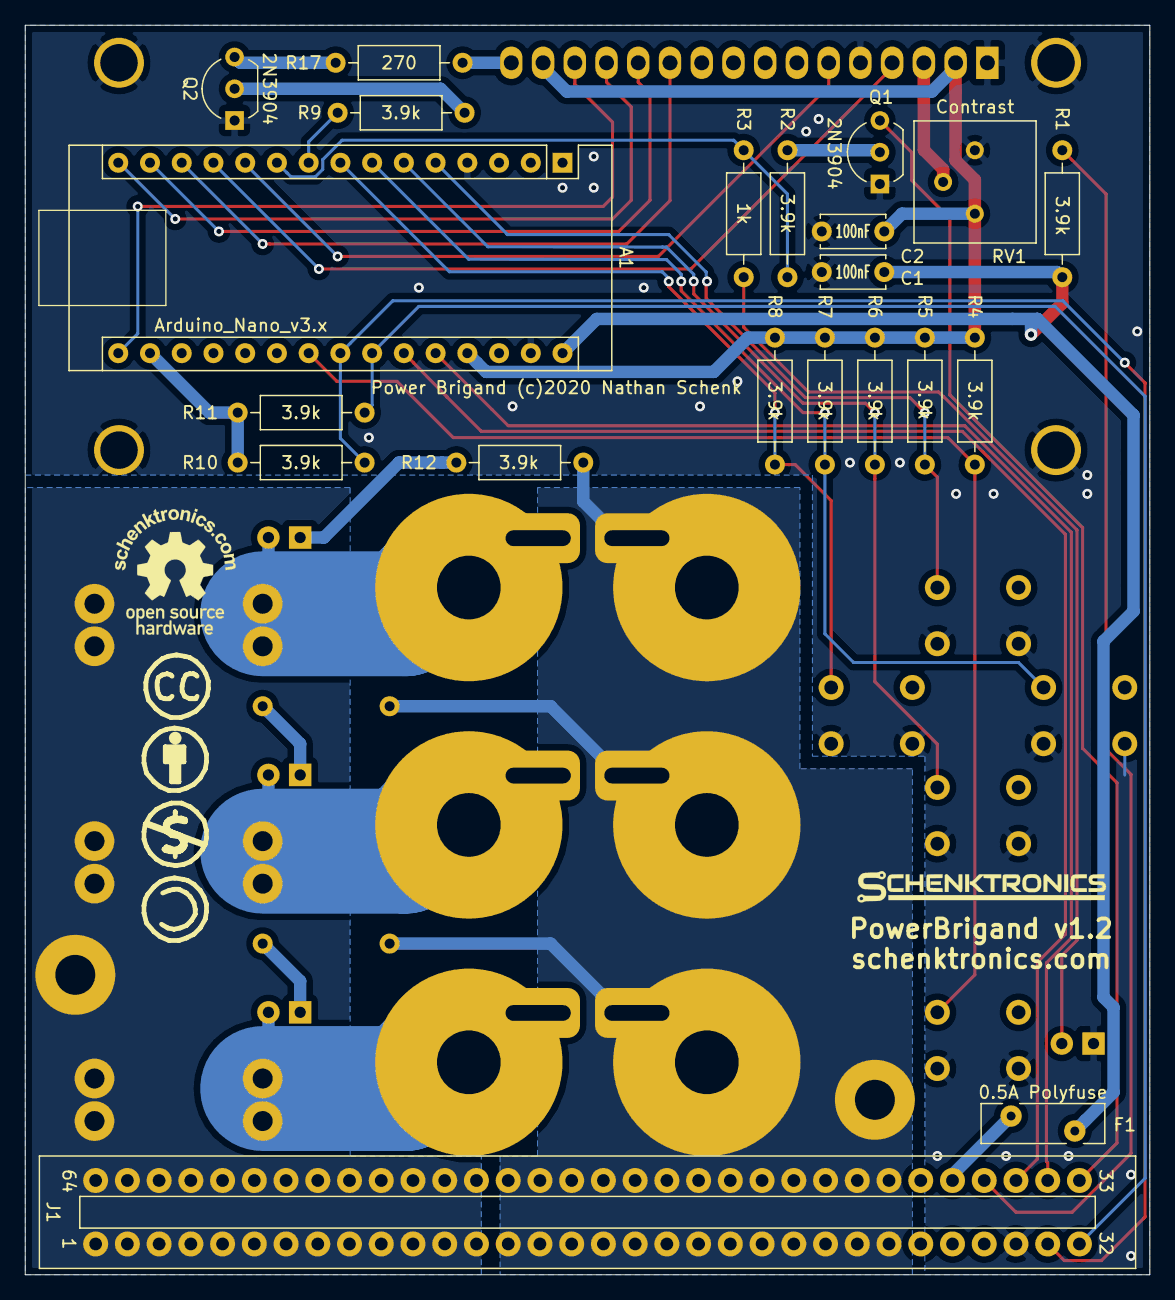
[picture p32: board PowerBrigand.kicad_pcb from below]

Board: 2 copper layers, 90.0 x 100.0 mm, 42 parts (21 on the bottom side), 38 nets.

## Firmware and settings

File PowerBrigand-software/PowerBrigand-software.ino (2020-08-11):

 /****************************************************************************************
 * This project is intended to read data from
 * and control an HP common slot power supply.
 * The interface is I2C and is somewhat similar to the PMBUS standard.
 * Copyright (c) 2020 Nathan Schenk
*****************************************************************************************/

/****************************************************************************************
 * Some power supplies have better low-current accuracy with the analog pin
 * 0    - Do not use the current monitoring pin
 * 1    - Settings optimized for 460W supplies
 * 254  - Measure analog output voltage directly.  Write it to the LCD and the serial port.
*****************************************************************************************/
#define powerSupplyType 0       //Power supply type


/****************************************************************************************
 * Personalize the boot screen
*****************************************************************************************/
 /*******************
 * 1234567890123456 *
 * Line1Message0123 *
 * Line2Message0123 *
 ********************/

#define bootMessage1 " Schenktronics  " //Boot message line 1
#define bootMessage2 " Power Brigand  " //Boot message line 2

/****************************************************************************************
 * Define Pin Numbers and constants
*****************************************************************************************/
//The addreses below are the i2c locations for the PSU control and PSU eeprom
#define eepromAddress 0x57
#define controlAddress 0x5F

//Define the LCD Pins
#define lcdBlPin        6       //Backlight Pin
#define lcdEnPin        8       //Enable Pin
#define lcdRsPin        9       //Register Select Pin
#define lcdD4Pin        10      //Data Bus 4 Pin
#define lcdD5Pin        11      //Data Bus 5 Pin
#define lcdD6Pin        12      //Data Bus 6 Pin
#define lcdD7Pin        13      //Data Bus 7 Pin

//Define the button pins
#define buttonUpPin     2       //Up button Pin
#define buttonDownPin   3       //Down button pin
#define buttonLeftPin   4       //Left button pin
#define buttonRightPin  5       //Right button pin
#define buttonOnOffPin  A3      //On/Off button pin

//Define the PSU interconnect pins
#define psOnPin         7       //Set high to turn on PSU
#define psOkPin         A6      //Analog value indicating PSU state
#define iMonPin         A7      //Analog value indicating PSU output current

/****************************************************************************************
 * Include Libraries
*****************************************************************************************/
//I2C library
//Built-In Arduino library
#include <Wire.h>

//Liquid Crystal Library
//Built-In Arduino Library
#include <LiquidCrystal.h>

//Button Library
//https://github.com/t3db0t/Button
#include <Button.h>


//registers.h is all the readable and writable datapoints for the PSU
#include "registers.h"

//https://github.com/rambo/I2C
//http://dsscircuits.com/index.php/articles/66-arduino-i2c-master-library
//#include <I2C.h>

/****************************************************************************************
 * Declare Global Variables
*****************************************************************************************/
//Set up LCD
LiquidCrystal lcd(lcdRsPin, lcdEnPin, lcdD4Pin, lcdD5Pin, lcdD6Pin, lcdD7Pin);
//Custom LCD characters
byte arrowUp[] = {
  B00100,
  B01010,
  B10101,
  B00100,
  B00100,
  B00100,
  B00000,
  B00000
};
byte arrowDown[] = {
  B00000,
  B00000,
  B00100,
  B00100,
  B00100,
  B10101,
  B01010,
  B00100
};

//Set up buttons
//Button(uint8_t buttonPin, uint8_t buttonMode, bool _debounceMode, int _debounceDuration);
Button buttonUp = Button(buttonUpPin, BUTTON_PULLUP_INTERNAL, true, 50);
Button buttonDown = Button(buttonDownPin, BUTTON_PULLUP_INTERNAL, true, 50);
Button buttonLeft = Button(buttonLeftPin, BUTTON_PULLUP_INTERNAL, true, 50);
Button buttonRight = Button(buttonRightPin, BUTTON_PULLUP_INTERNAL, true, 50);
Button buttonOnOff = Button(buttonOnOffPin, BUTTON_PULLUP_INTERNAL, true, 50);
bool buttonUpPressed;
bool buttonDownPressed;
bool buttonLeftPressed;
bool buttonRightPressed;
bool buttonRightHeld;
bool buttonOnOffPressed;
bool buttonOnOffHeld;
bool flash;
bool osrI2C;
//Analog input for current monitoring
float currentMonAnalog;


/****************************************************************************************
 * PSU Read and Write functions
*****************************************************************************************/

//read up to four bytes from the PSU and concat them into a 32 bit UINT
uint32_t readPSU(uint8_t address, uint8_t command, uint8_t bytes){
  uint8_t cs;
  uint8_t regCS;
  uint8_t readData[6];
  uint8_t i;
  uint32_t output;

  //protect memory
  if(bytes > 6){
    return 0xFFFFFFFF;
  }
  //Calculate the send checksum
  cs = command+(address<<1);
  regCS = ((0xFF-cs)+1)&0xFF;

  //write to bus
  Wire.beginTransmission(address);
  Wire.write(command);
  Wire.write(regCS);
  Wire.endTransmission(false);
  Wire.requestFrom(controlAddress,bytes+1);
  cs = 0;
  for(i = 0; i < bytes+1; i++){
    readData[i] = Wire.read();
    cs += readData[i];  //update the checksum
  }

  //Calculate the receive checksum
  regCS = ((0xFF-cs)+1)&0xFF;

  //Check to see if the checksum is correct
  if(regCS == 0){
    //concat the data into the output
    output = 0;
    for(i = 0; i < bytes; i++){
      output |= readData[i] << (8*i);
    }
    return output;
  }else{
    //If the checksum is not correct, return 0xFFFFFFFF
    return 0xFFFFFFFF;
    //return 0;
  }
}

//Writes a 16 bit word to the bus
void writePSU(uint8_t address, uint8_t command, uint16_t data){
  uint8_t cs;
  uint8_t regCS;
  uint8_t i;
  uint8_t dataLSB;
  uint8_t dataMSB;
  
  //split data up into 8 bit bytes
  dataLSB = data & 0xFF;
  dataMSB = data>>8;
  
  //Calculate checksum
  cs  = (address << 1) + command + dataLSB + dataMSB;
  regCS = ((0xFF-cs)+1)&0xFF;
  
  //write to bus
  Wire.beginTransmission(address);
  Wire.write(command);
  Wire.write(dataLSB);
  Wire.write(dataMSB);
  Wire.write(regCS);
  Wire.endTransmission(true);
}

/****************************************************************************************
 * Button Functions
*****************************************************************************************/
bool buttonPressed;
void onPress(Button& b){
  switch(b.pin){
    case buttonUpPin:
      buttonUpPressed = true;
    break;

    case buttonDownPin:
      buttonDownPressed = true;
    break;

    case buttonLeftPin:
      buttonLeftPressed = true;
    break;

    case buttonRightPin:
      buttonRightPressed = true;;
    break;

    case buttonOnOffPin:
      buttonOnOffPressed = true;
    break;

    default:
    break;
  }
  buttonPressed = 1;
}

void onHold(Button& b){
  switch(b.pin){
    case buttonRightPin:
      buttonRightHeld = true;
    break;

    case buttonOnOffPin:
      buttonOnOffHeld = true;
    break;

    default:
    break;
  }
}


//Read all the inputs
//Input Variables
//float readFlags;
float readInputVolts;
float readInputAmps;
float readInputWatts;
float readOutputVolts;
float readOutputAmps;
float readOutputWatts;
float readTempIntake; 
float readTempInternal;
float readFanSpeed;
//float readJoulesIn;
float readUpTime;
float readInputWattsMax;
float readInputAmpsMax;
float readOutputAmpsMax;

void readI2C(){
  uint32_t temp;
  uint8_t i;
  for(i = 0; i < 0x15; i++){
    switch(i){
      case 0:
//        temp = readPSU(controlAddress, reg_readFlags[0], reg_readFlags[2] );
//        if(temp != 0xFFFFFFFF){
//          readFlags = temp / (float)reg_readFlags[1];;
//        }
      break;
  
      case 1:
        temp = readPSU(controlAddress, reg_inputVolts[0], reg_inputVolts[2] );
        if(temp != 0xFFFFFFFF){
          readInputVolts = temp / (float)reg_inputVolts[1];;
        }
      break;
  
      case 2:
        temp = readPSU(controlAddress, reg_inputAmps[0], reg_inputAmps[2] );
        if(temp != 0xFFFFFFFF){
          readInputAmps = temp / (float)reg_inputAmps[1];;
        }
      break;
  
      case 3:
        temp = readPSU(controlAddress, reg_inputWatts[0], reg_inputWatts[2] );
        if(temp != 0xFFFFFFFF){
          readInputWatts = temp / (float)reg_inputWatts[1];;
        }
      break;
  
      case 4:
        temp = readPSU(controlAddress, reg_outputVolts[0], reg_outputVolts[2] );
        if(temp != 0xFFFFFFFF){
          readOutputVolts = temp / (float)reg_outputVolts[1];;
        }  
      break;
  
      case 5:
        temp = readPSU(controlAddress, reg_outputAmps[0], reg_outputAmps[2] );
        if(temp != 0xFFFFFFFF){
          readOutputAmps = temp / (float)reg_outputAmps[1];;
        }  
      break;
  
      case 6:
        temp = readPSU(controlAddress, reg_outputWatts[0], reg_outputWatts[2] );
        if(temp != 0xFFFFFFFF){
          readOutputWatts = temp / (float)reg_outputWatts[1];;
        }  
      break;
      
      case 7:
        temp = readPSU(controlAddress, reg_tempIntake[0], reg_tempIntake[2] );
        if(temp != 0xFFFFFFFF){
          readTempIntake = temp / (float)reg_tempIntake[1];;
        }  
      break;
  
      case 8:
        temp = readPSU(controlAddress, reg_tempInternal[0], reg_tempInternal[2] );
        if(temp != 0xFFFFFFFF){
          readTempInternal = temp / (float)reg_tempInternal[1];;
        }  
      break;
  
      case 9:
        temp = readPSU(controlAddress, reg_fanSpeed[0], reg_fanSpeed[2] );
        if(temp != 0xFFFFFFFF){
          readFanSpeed = temp / (float)reg_fanSpeed[1];;
        }  
      break;
  
      case 10:
  //      temp = readPSU(controlAddress, reg_joulesIn[0], reg_joulesIn[2] );
  //      if(temp != 0xFFFFFFFF){
  //        readJoulesIn = temp / (float)reg_joulesIn[1];;
  //      }  
      break;
  
      case 11:
        temp = readPSU(controlAddress, reg_upTime[0], reg_upTime[2] );
        if(temp != 0xFFFFFFFF){
          readUpTime = temp / (float)reg_upTime[1];;
        }  
      break;
  
      case 12:
        temp = readPSU(controlAddress, reg_inputWattsMax[0], reg_inputWattsMax[2] );
        if(temp != 0xFFFFFFFF){
          readInputWattsMax = temp / (float)reg_inputWattsMax[1];;
        }  
      break;
  
      case 13:
        temp = readPSU(controlAddress, reg_inputAmpsMax[0], reg_inputAmpsMax[2] );
        if(temp != 0xFFFFFFFF){
          readInputAmpsMax = temp / (float)reg_inputAmpsMax[1];;
        }  
      break;
  
      case 14:
        temp = readPSU(controlAddress, reg_outputAmpsMax[0], reg_outputAmpsMax[2] );
        if(temp != 0xFFFFFFFF){
          readOutputAmpsMax = temp / (float)reg_outputAmpsMax[1];;
        }  
      break;
  
      default:
      break;
      
    }
  }
}

/****************************************************************************************
 * LCD Functions
*****************************************************************************************/
//Initialize the LCD
void lcdInit() {
  // set up the LCD's number of columns and rows:
  lcd.begin(16, 2);
  //Initialize custom characters
  lcd.createChar(0, arrowUp);
  lcd.createChar(1, arrowDown);
}

//Splash screen the LCD when booting
 /*******************
 * 1234567890123456 *
 *  Schenktronics   *
 *  Power Brigand   *
 ********************/
void lcdSplash() {
  lcd.clear();                      //clear the display
  lcd.print(F(" Schenktronics  ")); //write the first line
  lcd.setCursor(0,1);               //Move curser to second line
  lcd.print(F(" Power Brigand  ")); //write the second line
}

//Custom LCD screen during boot
//Messages are defined at the top of the sketch
void lcdCustom() {
  lcd.clear();                      //clear the display
  lcd.print(F(bootMessage1)); //write the first line
  lcd.setCursor(0,1);               //Move curser to second line
  lcd.print(F(bootMessage2)); //write the second line
}

 //Output Page 1
 /*******************
 * 1234567890123456 *
 *  Output    xxxxW *
 * ˅xx.xxV xxx.xxA> *
 ********************/
void outputPage1() {
  static float val1 = 1;
  static float val2 = 1;
  static float val3 = 1;
  if((readOutputWatts != val1) || (readOutputVolts != val2) || (readOutputAmps != val3) || buttonPressed){
    lcd.home();
    lcd.print(F(" Output     "));
    lcd.setCursor(11,0);
    lcd.print(readOutputWatts,0);
    lcd.print(F("W      "));
    lcd.setCursor(0,1);
    lcd.write(byte(1));
    lcd.print(readOutputVolts,2);
    lcd.print(F("V       "));
    lcd.setCursor(9,1);
    lcd.print(readOutputAmps,2);
    lcd.print(F("A    "));
    lcd.setCursor(15,1);
    lcd.print(F(">"));
    val1=readOutputWatts;
    val2=readOutputVolts;
    val3=readOutputAmps;
  }
}
 
 //Output Page 2
 /*******************
 * 1234567890123456 *
 * Peak Out xxx.xxA *
 * <           Rst? *
 ********************/
void outputPage2() {
  static float val1 = 1;
  if((readOutputAmpsMax != val1) || buttonPressed){
    lcd.home();
    lcd.print(F("Peak Out        "));
    lcd.setCursor(9,0);
    lcd.print(readOutputAmpsMax,2);
    lcd.print(F("A     "));
    lcd.setCursor(0,1);
    //lcd.print(F("<           Rst?"));
    lcd.print(F("<               "));
    val1=readOutputAmpsMax;
  }
}

 //Input Page 1
 /*******************
 * 1234567890123456 *
 * ˄Input  xxxx.xxW *
 * ˅xxx.xxV xx.xxA >*
 ********************/
void inputPage1(){
  static float val1 = 1;
  static float val2 = 1;
  static float val3 = 1;
  if((readInputWatts != val1) || (readInputVolts != val2) || (readInputAmps != val3) || buttonPressed){
    lcd.home();
    lcd.write(byte(0));
    lcd.print(F("Input        "));
    lcd.setCursor(11,0);
    lcd.print(readInputWatts,0);
    lcd.print(F("W     "));
    lcd.setCursor(0,1);
    lcd.write(byte(1));
    lcd.print(readInputVolts);
    lcd.print(F("V         "));
    lcd.setCursor(9,1);
    lcd.print(readInputAmps);
    lcd.print(F("A      "));
    lcd.setCursor(15,1);
    lcd.print(F(">"));
    val1=readInputWatts;
    val2=readInputVolts;
    val3=readInputAmps;
  }
}

 //Input Page 2
 /*******************
 * 1234567890123456 *
 *  Peak In  xx.xxA *
 * < xxxx.xxW  Rst? *
 ********************/
void inputPage2(){
  static float val1 = 1;
  static float val2 = 1;
  if((readInputAmpsMax != val1) || (readInputWattsMax != val2) || buttonPressed){
    lcd.home();
    lcd.print(F("Peak In         "));
    lcd.setCursor(9,0);
    lcd.print(readInputAmpsMax);
    lcd.print(F("A"));
    lcd.setCursor(0,1);
    lcd.print(F("< "));
    lcd.print(readInputWattsMax);
    lcd.print(F("W               "));
    lcd.setCursor(12,1);
    //lcd.print(F("Rst?"));
    lcd.print(F("    "));
    val1=readInputAmpsMax;
    val2=readInputWattsMax;
  }
}

 //Temperature Page 1
 /*******************
 * 1234567890123456 *
 * ˄Intake xxx.xxC  *
 * ˅Exh    xxx.xxC> *
 ********************/
void temperaturePage1(){
  static float val1 = 1;
  static float val2 = 1;
  if((readTempIntake != val1) || (readTempInternal != val2) || buttonPressed){
    lcd.home();
    lcd.write(byte(0));
    lcd.print(F("Intake          "));
    lcd.setCursor(8,0);  
    lcd.print(readTempIntake);
    lcd.print(F("C"));
    lcd.setCursor(0,1);
    lcd.write(byte(1));
    lcd.print(F("Exh            "));
    lcd.setCursor(8,1);   
    lcd.print(readTempInternal);
    lcd.print(F("C"));
    lcd.setCursor(15,1);
    lcd.print(F(">"));
    val1=readTempIntake;
    val2=readTempInternal;
  }  
}

 //Temperature Page 2
 /*******************
 * 1234567890123456 *
 * Fan Speed        *
 * < xxxxxRPM       *
 ********************/
void temperaturePage2(){
  static float val1 = 1;
  if((readFanSpeed != val1) || buttonPressed){
    lcd.home();
    lcd.print(F("Fan Speed       "));
    lcd.setCursor(0,1);
    lcd.print(F("<               "));
    lcd.setCursor(2,1);
    lcd.print(readFanSpeed,0);
    lcd.print(F("RPM"));
    val1=readFanSpeed;
  }  
}

 //Info Page 1
 /*******************
 * 1234567890123456 *
 * ˄Uptime          *
 * xxxxxxxxxs       *
 ********************/
void infoPage1(){
  static float val1 = 1;
  if((readUpTime != val1) || buttonPressed){
    lcd.home();
    lcd.write(byte(0));
    lcd.print(F("Uptime          "));
    lcd.setCursor(0,1);
    lcd.print(F("                "));
    lcd.setCursor(1,1);
    lcd.print(readUpTime,0);
    lcd.print(F("s"));
    val1=readUpTime;
  }
}


//LCD State Machine 
void lcdStateMachine(){
  //Row and column below define the "Page" for the lcd.
  //Imagine the pages are layed out in a grid
  static uint8_t row;
  static uint8_t column;
  static bool ons;

  //Handle buttons
  if(buttonUpPressed && (column == 0)){
    row--;
  }
  if(buttonDownPressed && (column == 0)){
    row++;
    buttonPressed=1;
  }
  if(buttonRightPressed){
    column++;
  }
  if(buttonLeftPressed){
    column--;
  }
  
  //Start of state machine
    switch(row){
      //Displays outptus
      case 0:
        switch(column){
          case 0:
            outputPage1();
          break;
  
          case 1:
            outputPage2();
          break;
  
          default:
            if(column == 0xFF){
              column = 0;
            }else{
              column--;
            }
          break;
        }
      break;
      
      //Displays inputs
      case 1:
        switch(column){
          case 0:
            inputPage1();
          break;
            
          case 1:
            inputPage2();
          break;
  
          default:
            if(column == 0xFF){
              column = 0;
            }else{
              column--;
            }
          break;
        }
      break;
      
      //Displays thermal info
      case 2:
        switch(column){
          case 0:
            temperaturePage1();
          break;
  
          case 1:
            temperaturePage2();
          break;
  
          default:
            if(column == 0xFF){
              column = 0;
            }else{
              column--;
            }
          break;
        }
      break;

      //Displays thermal info
      case 3:
        switch(column){
          case 0:
            infoPage1();
          break;
    
          default:
            if(column == 0xFF){
              column = 0;
            }else{
              column--;
            }
          break;
        }
      break;
  
      default:
        if(row == 0xFF){
          row = 0;
        }else{
          row--;
        }
      break;
    }
}

//Override current and wattage for certain power supplies


//Use this function to set up a flasher for LED's and stuff
bool flasher(uint16_t setpoint){
  static bool flasherBool = 0;
  static long flasherChangeTime;
  static long flasherCurrentTime;
  flasherCurrentTime = millis(); //get the current time so millis doesn't need to be called too often.
  if(!flasherBool){
    if(flasherCurrentTime - flasherChangeTime >= setpoint){
      flasherBool = !flasherBool;
      flasherChangeTime = flasherCurrentTime;
    }
  }else{
    if(flasherCurrentTime - flasherChangeTime >= setpoint){
      flasherBool = !flasherBool;
      flasherChangeTime = flasherCurrentTime;
    }
  }
  return flasherBool;
}


/****************************************************************************************
 * setup() and loop()  "Where the code goes"
*****************************************************************************************/
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
void loop() {
  //flasher
  flash = flasher(250);
  
  //update the buttons
  buttonPressed = false;
  buttonUpPressed = false;
  buttonDownPressed = false;
  buttonLeftPressed = false;
  buttonRightPressed = false;
  buttonOnOffPressed = false;
  buttonRightHeld = false;
  buttonOnOffHeld = false;
  buttonLeft.process();
  buttonRight.process();
  buttonUp.process();
  buttonDown.process();
  buttonOnOff.process();

  //read all the inputs

  if(flash && !osrI2C){
    readI2C();


    switch(powerSupplyType){
      //460W HSTNS-PL14 power supply = 90mV/A
      //This power supply has the following minimum values:
      //Output Amps: 0.0A
      //Output Watts: 36W
      //Input Watts: 50W
      case 1:
        currentMonAnalog = ((analogRead(iMonPin)*1.1)/1024.0)/0.090;
        //Override the i2c if the read current is less than 10A
        if(readOutputAmps <= 5.0){
          readOutputAmps = currentMonAnalog;
        } 
        //If the output wattage from i2c is less than 50, calculate it.
        if(readOutputWatts <= 36.0){
          readOutputWatts = readOutputVolts * readOutputAmps;
        }
        //If the input wattage from i2c is less than 50, calculate it.
        if(readInputWatts <= 50.0){
          readInputWatts = readInputVolts * readInputAmps;
        }
        //Serial.print("I2C:");
        //Serial.print(readOutputAmps);
        //Serial.print("A  Analog:");
        //Serial.print(currentMonAnalog);
        //Serial.println("A");
      break;

      //Measure analog current output voltage for testing purposes
      case 254:
          currentMonAnalog = ((analogRead(iMonPin)*1.1)/1024.0);
          Serial.println(currentMonAnalog,4);
          readOutputAmps = currentMonAnalog;
      break;

      default:
      break;
    }
  }
  osrI2C = flash;
  

  //LCD state machine
  lcdStateMachine();

  //Turn on/off the PSU
  if(buttonOnOffPressed){
    digitalWrite(psOnPin, HIGH);
  }
  if(buttonOnOffHeld){
    digitalWrite(psOnPin, LOW);
  }

}

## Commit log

2020-08-08 add case
    [backplate.dxf, faceplate_2anderson_1BindingPost.dxf]
2020-08-08 add PCB
    [PowerBrigand.kicad_pcb, PowerBrigand.sch]
2020-08-08 add schematic pdf
2020-08-08 update license
    [PowerBrigand.kicad_pcb, PowerBrigand.sch]
2020-08-08 move PCB and schematic .pdf's back into pcb folder
2020-08-11 set default power supply type to zero

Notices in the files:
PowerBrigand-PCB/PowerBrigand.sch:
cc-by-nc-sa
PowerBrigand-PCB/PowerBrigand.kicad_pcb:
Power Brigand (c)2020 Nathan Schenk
